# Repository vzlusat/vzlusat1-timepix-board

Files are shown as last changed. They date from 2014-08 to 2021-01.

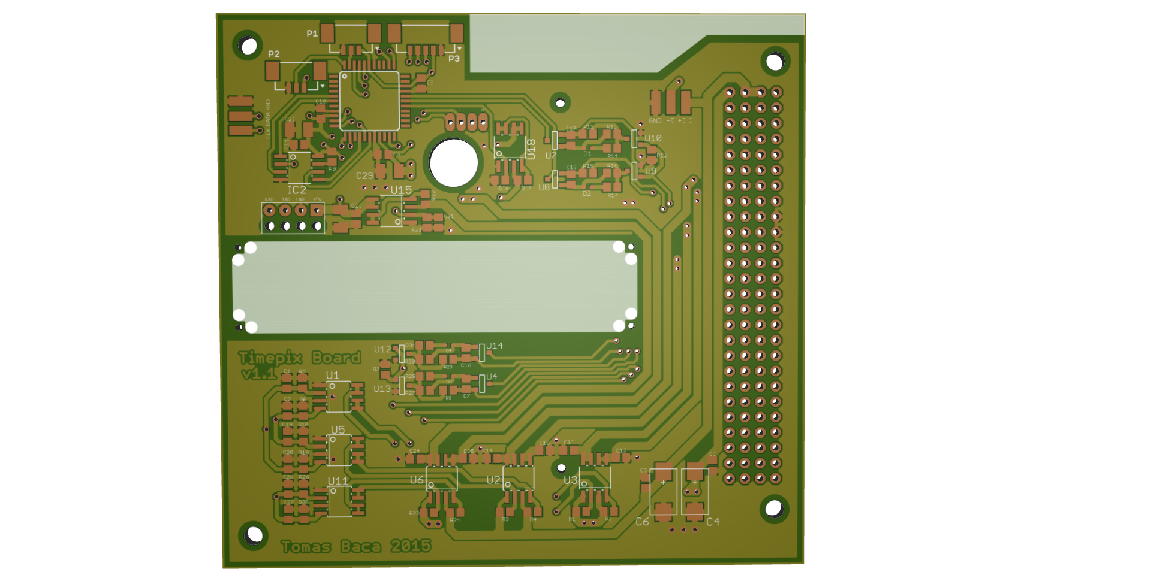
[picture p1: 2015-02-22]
hardware/timepix_board/timepix_board_board.png

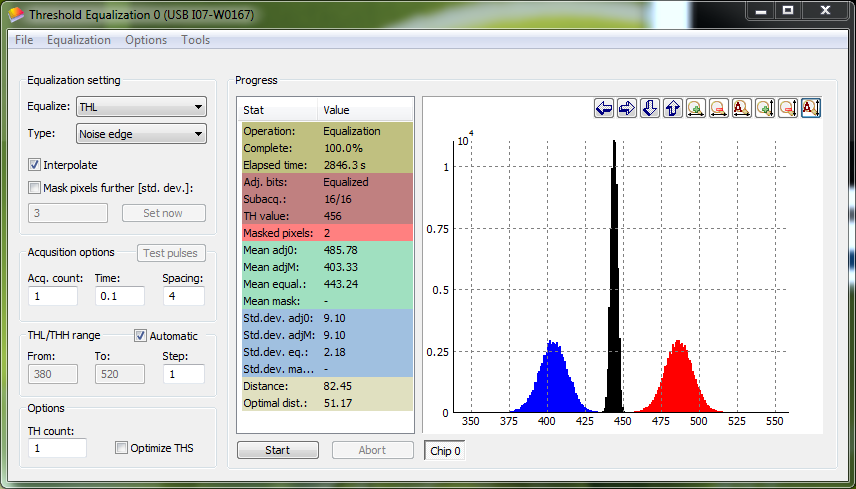
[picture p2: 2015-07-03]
software/EqualizationParser/equalization_fligh_model/equalization.PNG

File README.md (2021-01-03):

# VZLUSAT-1 Timepix board materials

## Publications

```
Baca, T., et al.
"Timepix in LEO Orbit onboard the VZLUSAT-1 Nanosatellite:
1-year of Space Radiation Dosimetry Measurements."
Journal of Instrumentation 13.11 (2018): C11010.
```

```
Baca, T., et al.
"Miniaturized X-ray telescope for VZLUSAT-1 nanosatellite with Timepix detector."
Journal of Instrumentation 11.10 (2016): C10007.
```

```
Urban, Martin, et al.
"VZLUSAT-1: Nanosatellite with miniature lobster eye X-ray telescope
and qualification of the radiation shielding composite for space application."
Acta Astronautica 140 (2017): 96-104.
```

```
Daniel, Vladimír, et al.
"In-Orbit Commissioning of Czech Nanosatellite VZLUSAT-1 for the QB50 Mission
with a Demonstrator of a Miniaturised Lobster-Eye X-Ray Telescope
and Radiation Shielding Composite Materials."
Space Science Reviews 215.5 (2019): 40.
```

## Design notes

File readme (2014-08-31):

The pure core of FreeRTOS with drivers used on ATXMega128A4U in the VZLUSat project.

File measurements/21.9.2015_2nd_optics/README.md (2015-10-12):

Měření 21.9.2015
================

Probíhalo testování nové (druhé) x-ray optiky v komeře v Rigaku.

Legenda je v mereni_21.9.2015.pdf

- EQM deska s letovým firmware
- nejdříve měření před odsátím atmosféry, s proudem do x-ray zdroje 0.1mA, timepix v čítacím módu, expozice od 1ms do 100ms
- poté několik měření se zaplou filtrací během odsávání atmosfery s expozicí 1ms, poud 0.01mA, čítací mód
- nakonec ve vakuu průběh expozic od 1ms do 100ms s proudem 0.1mA, čítacím módem

snímek #625 s umístěným výkonným nelegálním zářičem za medipixem (mimo komoru) 

legenda k názvům souborů:
- _1 je originální (nezmenšený) snímek
- _2 je binning8
- _4 je binning16
- _8 je binning32
- _16 jsou součty řádků a sloupců
- _32 je energetický histogram

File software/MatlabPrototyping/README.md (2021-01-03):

# A prototyping Matlab control scripts for the Timepix board

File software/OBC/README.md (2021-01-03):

# OBC-side of the Timepix board software API

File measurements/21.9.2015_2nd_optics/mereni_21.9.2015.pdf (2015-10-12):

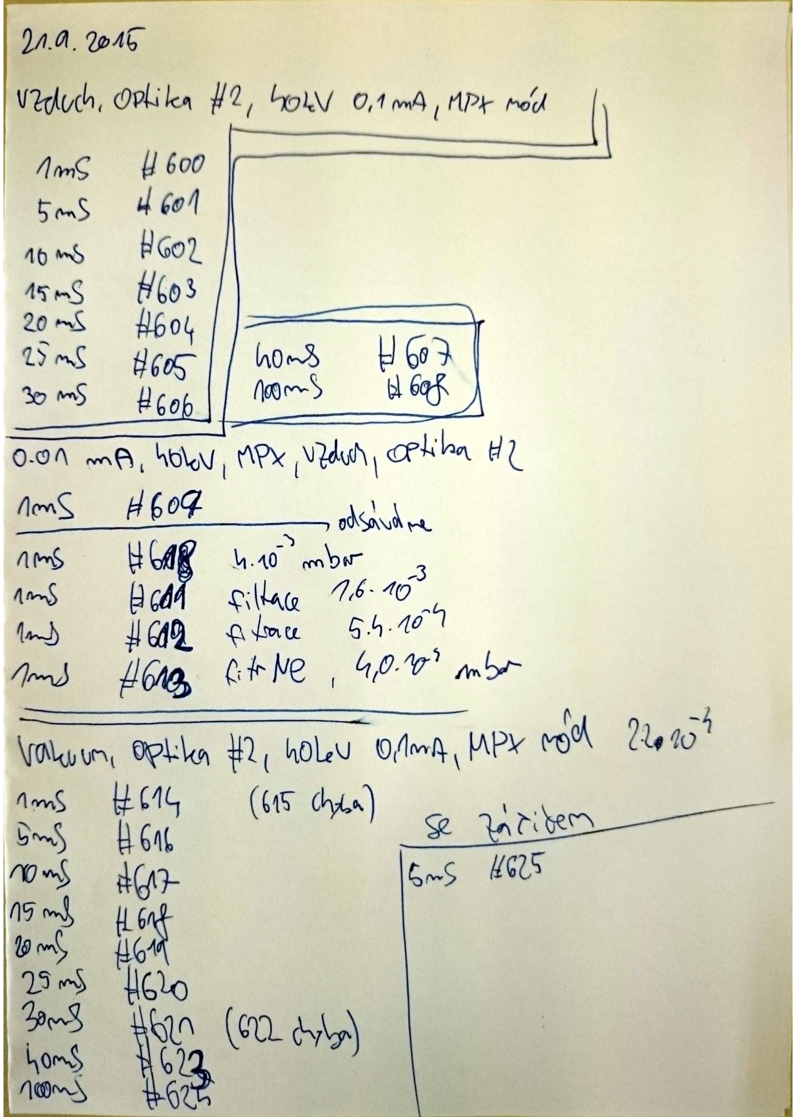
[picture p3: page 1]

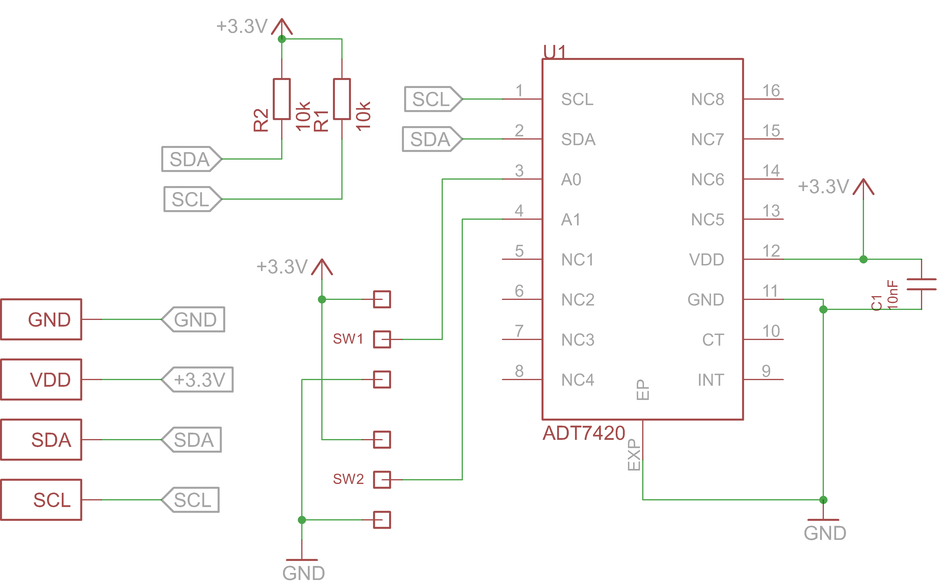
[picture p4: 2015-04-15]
hardware/ADT7420_board/therm_board_schema.png

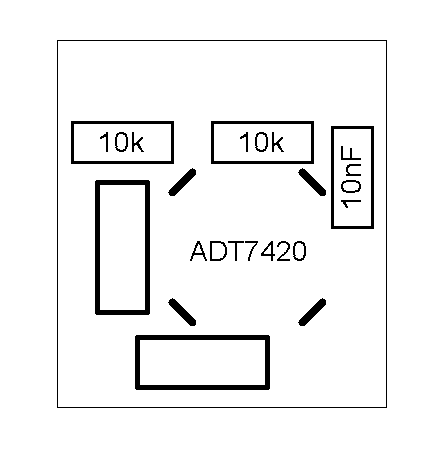
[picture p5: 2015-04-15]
hardware/ADT7420_board/therm_board_osazovak.png

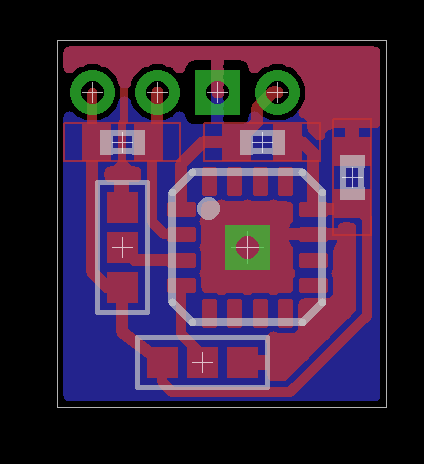
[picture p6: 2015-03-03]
hardware/ADT7420_board/therm_board.png

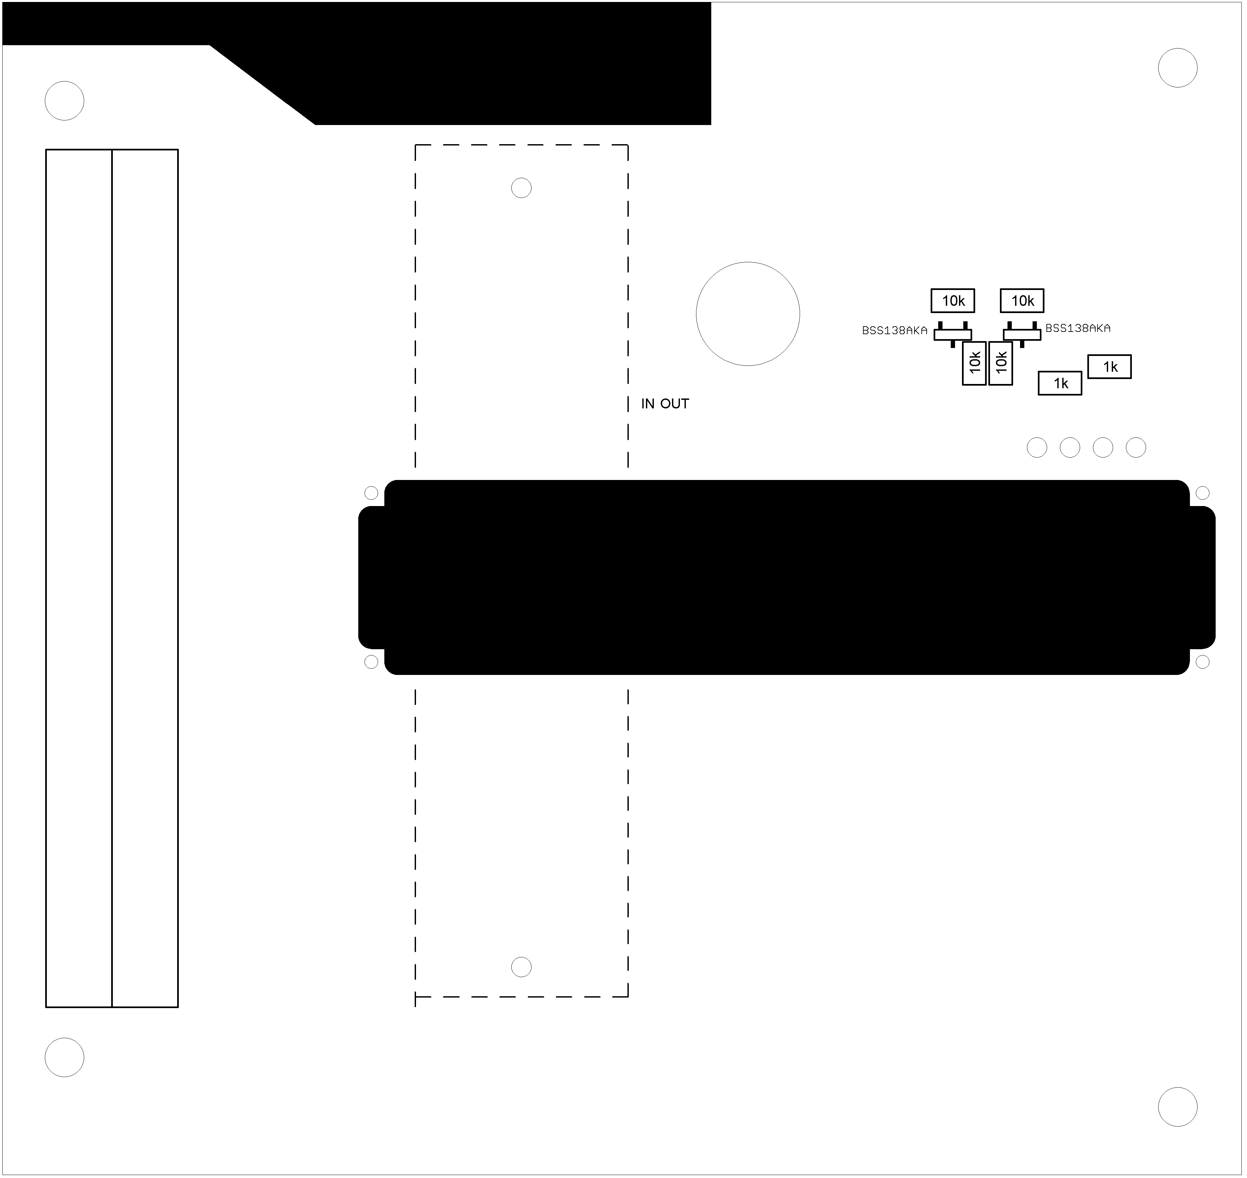
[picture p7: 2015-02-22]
hardware/timepix_board/part_bottom.png

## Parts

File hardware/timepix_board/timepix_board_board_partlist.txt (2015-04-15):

Partlist

Exported from medipix.sch at 19.3.2015 9:49:41

EAGLE Version 6.5.0 Copyright (c) 1988-2013 CadSoft

Assembly variant: 

Part     Value             Device             Package           Library             Sheet

C1       100n              CAPACITOR_CERAMIC  R0805             medipix             1
C2       100n              CAPACITOR_CERAMIC  R0805             medipix             1
C3       100n              CAPACITOR_CERAMIC  R0805             medipix             1
C4       220u              CAPACITOR_TANTAL_D D                 medipix             1
C5       100n              CAPACITOR_CERAMIC  R0805             medipix             1
C6       220u              CAPACITOR_TANTAL_D D                 medipix             1
C7       15nF              CAPACITOR_CERAMIC  R0805             medipix             1
C8       100n              CAPACITOR_CERAMIC  R0805             medipix             1
C9       100n              CAPACITOR_CERAMIC  R0805             medipix             1
C10      100n              CAPACITOR_CERAMIC  R0805             medipix             1
C11      100n              CAPACITOR_CERAMIC  R0805             medipix             1
C12      100n              CAPACITOR_CERAMIC  R0805             medipix             1
C13      100n              CAPACITOR_CERAMIC  R0805             medipix             1
C14      100n              CAPACITOR_CERAMIC  R0805             medipix             1
C15      100n              CAPACITOR_CERAMIC  R0805             medipix             1
C16      15nF              CAPACITOR_CERAMIC  R0805             medipix             1
C17      15nF              CAPACITOR_CERAMIC  R0805             medipix             1
C18      15nF              CAPACITOR_CERAMIC  R0805             medipix             1
C19      100n              CAPACITOR_CERAMIC  R0805             medipix             1
C20      100n              CAPACITOR_CERAMIC  R0805             medipix             1
C21      100n              CAPACITOR_CERAMIC  R0805             medipix             1
C22      100u              CAPACITOR_TANTAL_B SMC_B             medipix             1
C23      100n              CAPACITOR_CERAMIC  R0805             medipix             1
C24      100n              CAPACITOR_CERAMIC  R0805             medipix             1
C25      100n              CAPACITOR_CERAMIC  R0805             medipix             1
C26      100n              CAPACITOR_CERAMIC  R0805             medipix             1
C27      100n              CAPACITOR_CERAMIC  R0805             medipix             1
C28      100u              CAPACITOR_TANTAL_B SMC_B             medipix             1
C29      100u              CAPACITOR_TANTAL_B SMC_B             medipix             1
CLK      CLK               PIN                PIN               medipix             1
D1       BAS70             BAS70              SOD523            medipix             1
D2       BAS70             BAS70              SOD523            medipix             1
D3       BAS70             BAS70              SOD523            medipix             1
D4       BAS70             BAS70              SOD523            medipix             1
DATA     DATA              PIN                PIN               medipix             1
GND      GND               PIN                PIN               medipix             1
GND1     GND               PIN                PIN               medipix             1
GND25    +3.3              PIN                PIN               medipix             1
GND28    +5                PIN                PIN               medipix             1
H1       H1                H1                 H-KONEKTOR        medipix             1
H2       H2                H2                 H-KONEKTOR        medipix             1
IC1      AVR_XMEGA_A4U44A  AVR_XMEGA_A4U44A   TQFP44            medipix             1
IC2      FM25H20           FM25H20            SOIC08            medipix             1
MP       MEDIPIX_CONNECTOR MEDIPIX_CONNECTOR  MEDIPIX_CONNECTOR medipix             1
P1       PICOBLADE         53398-0310         53398-0310        con-molex-picoblade 1
P2       PICOBLADE         53398-0310         53398-0310        con-molex-picoblade 1
P3       PICOBLADE         53398-0510         53398-0510        con-molex-picoblade 1
R1       100k              RESISTOR0805       R0805             medipix             1
R2       100k              RESISTOR0805       R0805             medipix             1
R3       100k              RESISTOR0805       R0805             medipix             1
R4       100k              RESISTOR0805       R0805             medipix             1
R5       100k              RESISTOR0805       R0805             medipix             1
R6       100k              RESISTOR0805       R0805             medipix             1
R7       100k              RESISTOR0805       R0805             medipix             1
R8       100k              RESISTOR0805       R0805             medipix             1
R9       100k              RESISTOR0805       R0805             medipix             1
R10      100k              RESISTOR0805       R0805             medipix             1
R11      100k              RESISTOR0805       R0805             medipix             1
R12      100k              RESISTOR0805       R0805             medipix             1
R13      330k              RESISTOR0805       R0805             medipix             1
R14      1k5               RESISTOR0805       R0805             medipix             1
R15      100k              RESISTOR0805       R0805             medipix             1
R16      330k              RESISTOR0805       R0805             medipix             1
R17      1k5               RESISTOR0805       R0805             medipix             1
R18      100k              RESISTOR0805       R0805             medipix             1
R19      10k               RESISTOR0805       R0805             medipix             1
R20      10k               RESISTOR0805       R0805             medipix             1
R21      100k              RESISTOR0805       R0805             medipix             1
R22      100k              RESISTOR0805       R0805             medipix             1
R23      100k              RESISTOR0805       R0805             medipix             1
R24      100k              RESISTOR0805       R0805             medipix             1
R25      100k              RESISTOR0805       R0805             medipix             1
R26      100k              RESISTOR0805       R0805             medipix             1
R27      330k              RESISTOR0805       R0805             medipix             1
R28      1k5               RESISTOR0805       R0805             medipix             1
R29      100k              RESISTOR0805       R0805             medipix             1
R30      330k              RESISTOR0805       R0805             medipix             1
R31      1k5               RESISTOR0805       R0805             medipix             1
R32      10k               RESISTOR0805       R0805             medipix             1
R33      10k               RESISTOR0805       R0805             medipix             1
R34      1k                RESISTOR0805       R0805             medipix             1
R35      1k                RESISTOR0805       R0805             medipix             1
R36      100k              RESISTOR0805       R0805             medipix             1
R37      100k              RESISTOR0805       R0805             medipix             1
TXD1     IN                PIN                PIN               medipix             1
TXD2     OUT               PIN                PIN               medipix             1
U$1      THERM             THERM              THERM             medipix             1
U1       IRF7313           IRF7313            SOIC08            medipix             1
U2       IRF7328           IRF7328            SOIC08            medipix             1
U3       IRF7328           IRF7328            SOIC08            medipix             1
U4       BSS84             BSS84              SOT-23            medipix             1
U5       IRF7313           IRF7313            SOIC08            medipix             1
U6       IRF7328           IRF7328            SOIC08            medipix             1
U7       BSS84             BSS84              SOT-23            medipix             1
U8       BSS84             BSS84              SOT-23            medipix             1
U9       BSS138AKA         BSS138AKA          SOT-23            medipix             1
U10      BSS138AKA         BSS138AKA          SOT-23            medipix             1
U11      IRF7313           IRF7313            SOIC08            medipix             1
U12      BSS138AKA         BSS138AKA          SOT-23            medipix             1
U13      BSS138AKA         BSS138AKA          SOT-23            medipix             1
U14      BSS84             BSS84              SOT-23            medipix             1
U15      IRF7319           IRF7319            SOIC08            medipix             1
U16      BSS138AKA         BSS138AKA          SOT-23            medipix             1
U17      BSS138AKA         BSS138AKA          SOT-23            medipix             1
U18      IRF7319           IRF7319            SOIC08            medipix             1

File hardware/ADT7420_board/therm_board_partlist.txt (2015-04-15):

Partlist

Exported from thermo_board.brd at 19.3.2015 9:47:04

EAGLE Version 6.5.0 Copyright (c) 1988-2013 CadSoft

Assembly variant: 

Part     Value             Package         Library    Position (inch)       Orientation

C1       10nF              R0402           thermo_lib (0.295 0.23)          R270
R1       10k               R0402           thermo_lib (0.205 0.265)         R0
R2       10k               R0402           thermo_lib (0.065 0.265)         R180
U1       ADT7420           LFCSP16         thermo_lib (0.19 0.16)           R0

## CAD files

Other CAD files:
hardware/cooler/cooler1.dwg
software/usb_lite_firmware_modified/Medipix.OBJ

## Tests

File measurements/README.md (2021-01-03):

# Measurement during prototyping

The orbital measurements can be proccessed using [https://github.com/vzlusat/vzlusat1-timepix-decoder](https://github.com/vzlusat/vzlusat1-timepix-decoder) and found here processed: [https://github.com/vzlusat/vzlusat1-timepix-data](https://github.com/vzlusat/vzlusat1-timepix-data)

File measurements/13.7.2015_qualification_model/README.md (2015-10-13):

Měření 13.7.2015
================

Legenda je uložena v mereni-13.7.2015-EQM.pdf

Probíhalo měření v komoře v Rigaku s EQM HW, ve vakuu a bez optiky.

Nejdříve bylo uděláno pár snímku před a během odčerpávání vzduchu z komory.

Všechna měření, až na poslední (vyznačené v legendě) jsou s výkonem x-ray zdroje 40kV, 0.1mA, poslední je s 0.01mA.

Měření se stává z několika sérií s expozicemi od 1ms do 10 až 30ms.

Všchna měření měla zaplou filtraci, nicméně mimo post-processovaného výstupu se ukládaly i originální snímky (soubory s _o).

Konvence pojmenování souborů: soubor s "o" nakonci (např. image_513o.mat) obsahuje originální snímek, soubor s "p" nakonci (image_513p.mat) obsahuje příslušný zpracovaný snímek (tedy postprocess, filtrace, zmenšenina, podle toho, co bylo zapnuté).

POZOR, BĚHEM TOHOTO MěřENí BYLA V SOFTWARU CHYBA, V TOT REžIMU SE ZAOKROUHLOVALO DOLU, TEDY ZMIZELY PIXELI S ENERGIí < 43. MěřENí V MÓDU MPX JSOU V POřáDKU.

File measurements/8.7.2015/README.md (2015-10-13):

Měření 8.7.2015
================

Legenda se nachází v mereni_8.7.2015.pdf

Probíhalo měření v komoře v Rigaku s EQM HW, na vzduchu, nejdříve s a poté bez krycího sklíčka na detektoru.

POZOR, BĚHEM TOHOTO MěřENí BYLA V SOFTWARU CHYBA, V TOT REžIMU SE ZAOKROUHLOVALO DOLU, TEDY ZMIZELY PIXELI S ENERGIí < 43. MěřENí V MÓDU MPX JSOU V POřáDKU.

Nejdříve bylo uděláno pár snímku před a po sundání krycího sklíčka.

Zajímavé (srovnatelné) jsou tedy snímky 420, 422 a 423, které jsou v MPX módu a bez krycího sklíčka.

Poté jsme se jali měřiti s optikou. Ukládány byly různé varianty výstupu pro expozice od 1ms do 200ms, vše na vzduchu a s filtrací.

Snímky pravděpodobně nejsou vhodné pro srovnání vzhledem k expozici ve vzduchu.

Konvence pojmenování souborů: soubor s "o" nakonci (např. image_513o.mat) obsahuje originální snímek, soubor s "p" nakonci (image_513p.mat) obsahuje příslušný zpracovaný snímek (tedy postprocess, filtrace, zmenšenina, podle toho, co bylo zapnuté).

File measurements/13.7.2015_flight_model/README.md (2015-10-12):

Měření 13.7.2015
================

Měření s tohoto dne se zaměřovala na test letového hardwaru. 

POZOR, BĚHEM TOHOTO MěřENí BYLA V SOFTWARU CHYBA, V TOT REžIMU SE ZAOKROUHLOVALO DOLU, TEDY ZMIZELY PIXELI S ENERGIí < 43. MěřENí V MÓDU MPX JSOU V POřáDKU.

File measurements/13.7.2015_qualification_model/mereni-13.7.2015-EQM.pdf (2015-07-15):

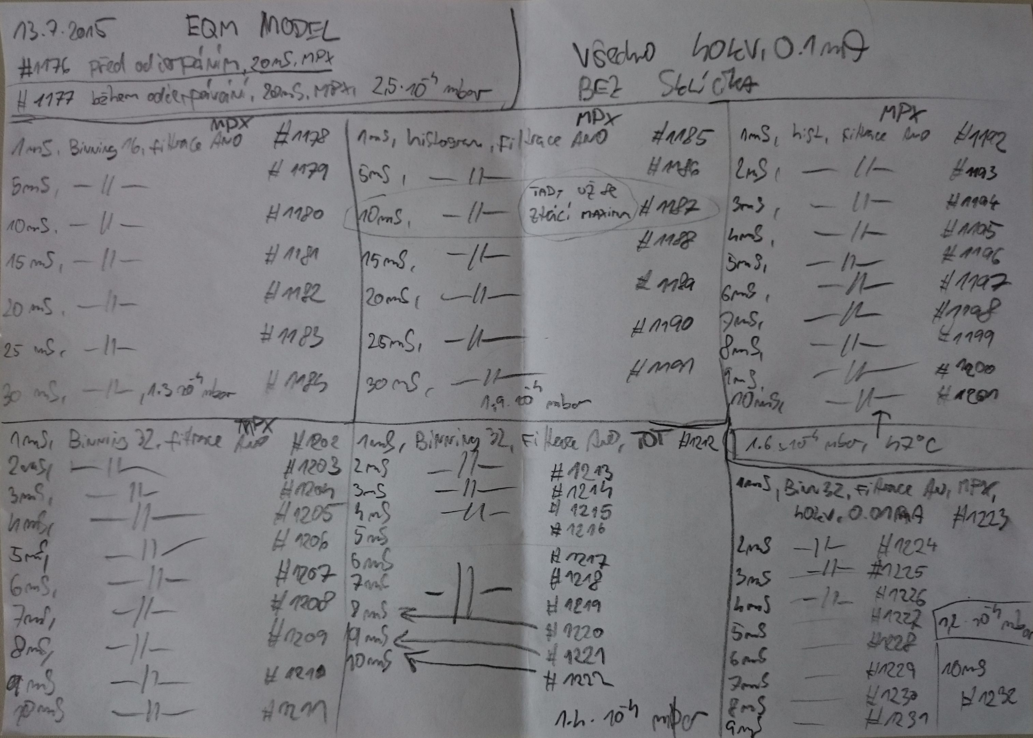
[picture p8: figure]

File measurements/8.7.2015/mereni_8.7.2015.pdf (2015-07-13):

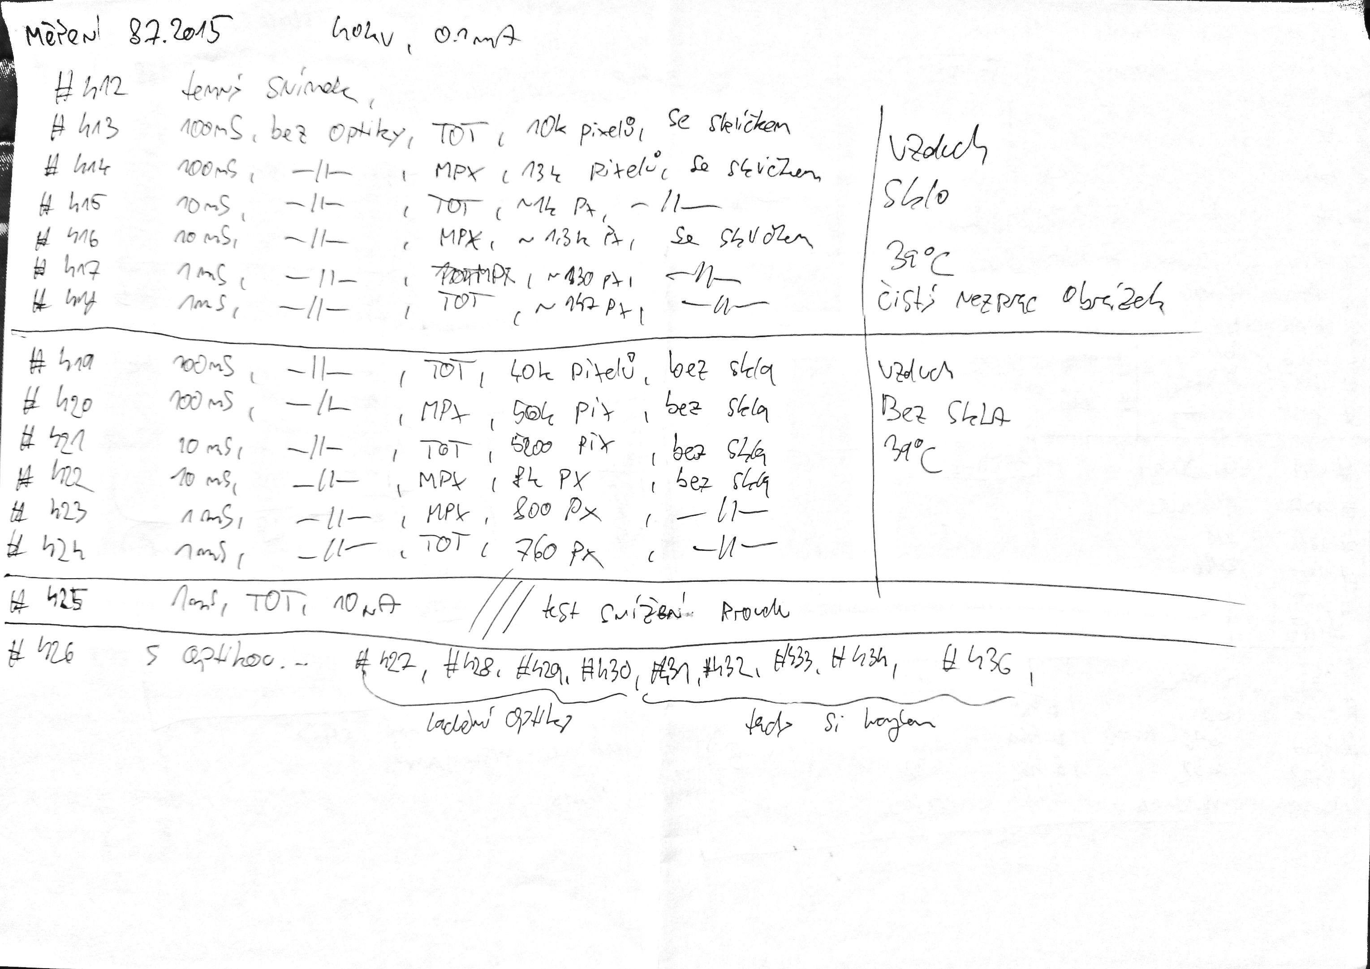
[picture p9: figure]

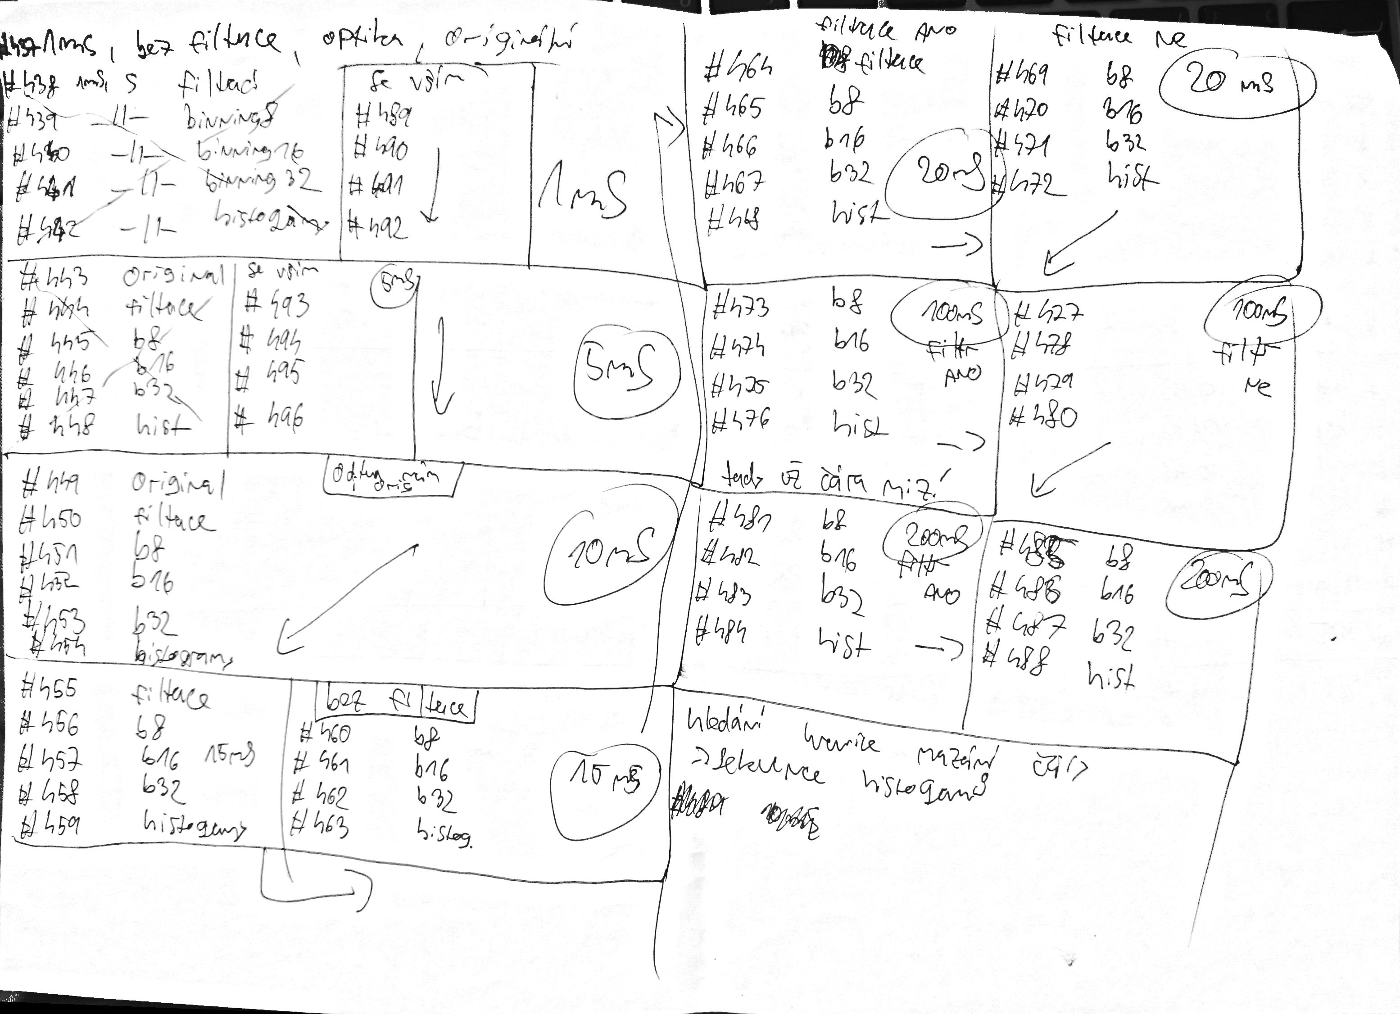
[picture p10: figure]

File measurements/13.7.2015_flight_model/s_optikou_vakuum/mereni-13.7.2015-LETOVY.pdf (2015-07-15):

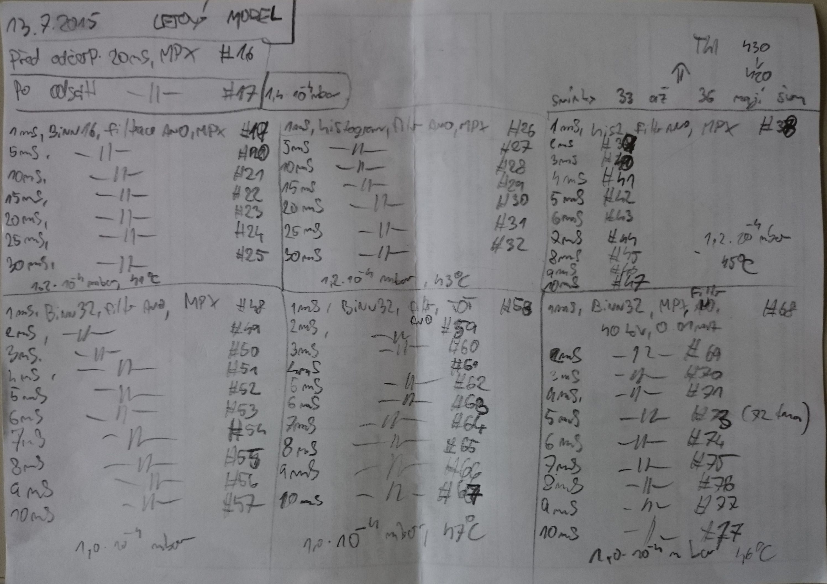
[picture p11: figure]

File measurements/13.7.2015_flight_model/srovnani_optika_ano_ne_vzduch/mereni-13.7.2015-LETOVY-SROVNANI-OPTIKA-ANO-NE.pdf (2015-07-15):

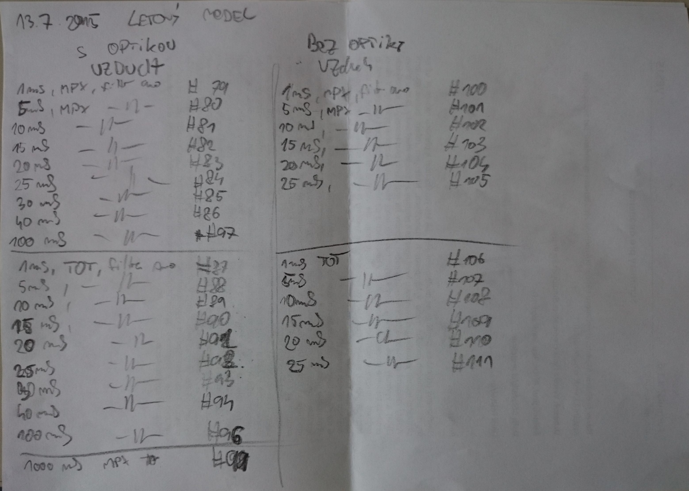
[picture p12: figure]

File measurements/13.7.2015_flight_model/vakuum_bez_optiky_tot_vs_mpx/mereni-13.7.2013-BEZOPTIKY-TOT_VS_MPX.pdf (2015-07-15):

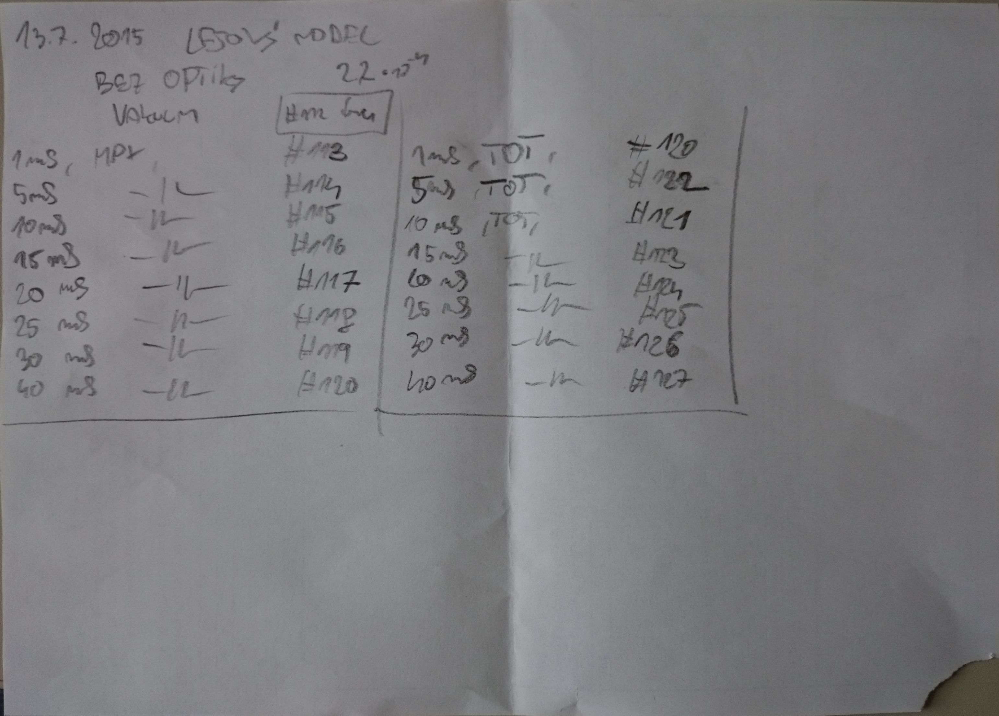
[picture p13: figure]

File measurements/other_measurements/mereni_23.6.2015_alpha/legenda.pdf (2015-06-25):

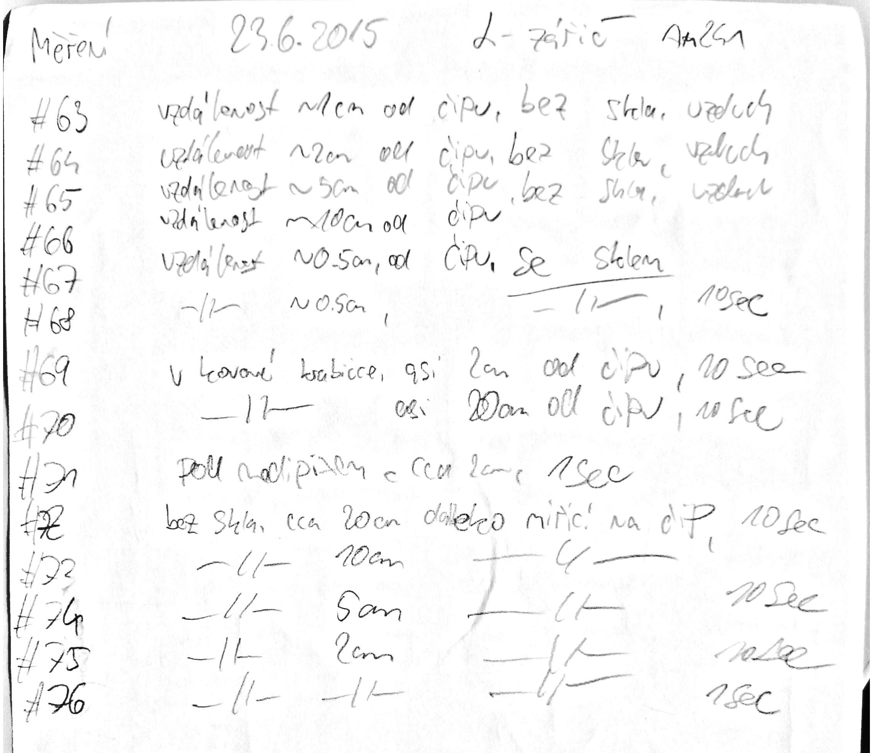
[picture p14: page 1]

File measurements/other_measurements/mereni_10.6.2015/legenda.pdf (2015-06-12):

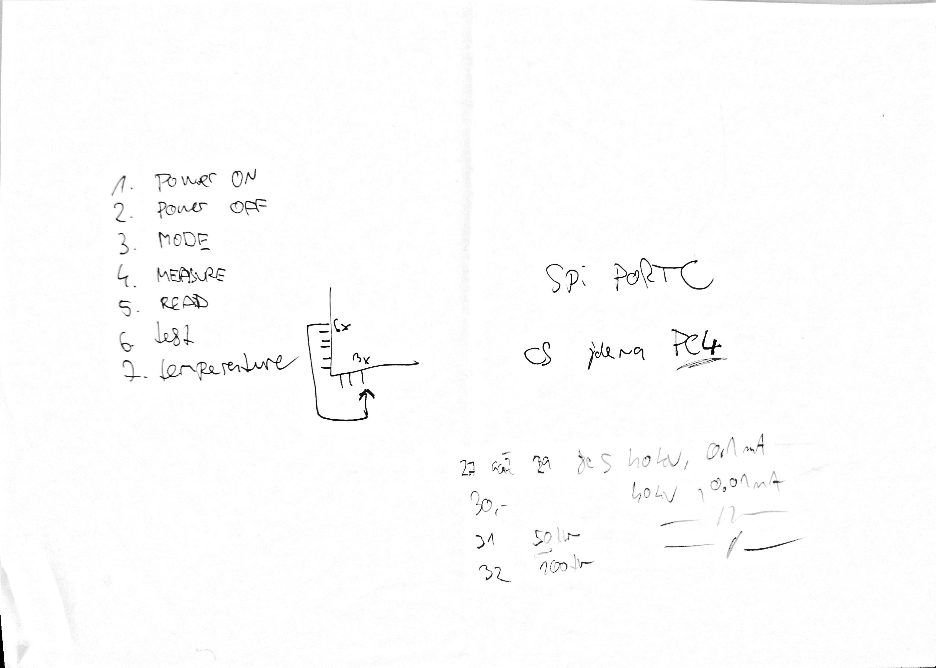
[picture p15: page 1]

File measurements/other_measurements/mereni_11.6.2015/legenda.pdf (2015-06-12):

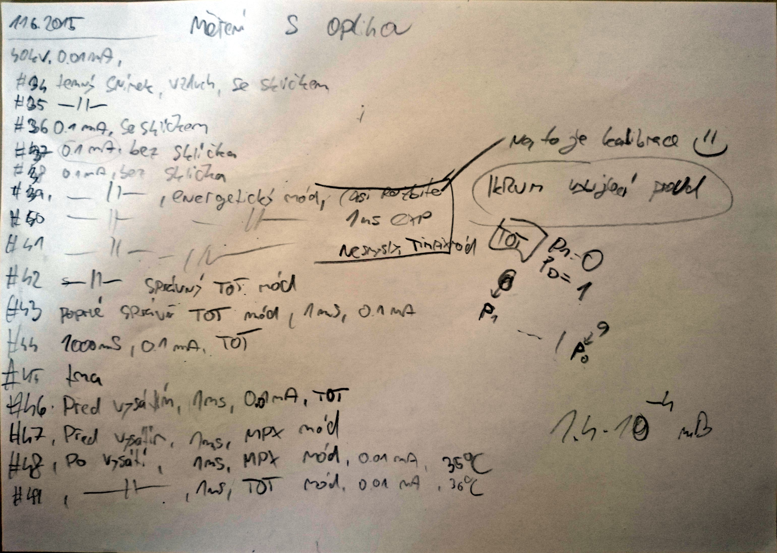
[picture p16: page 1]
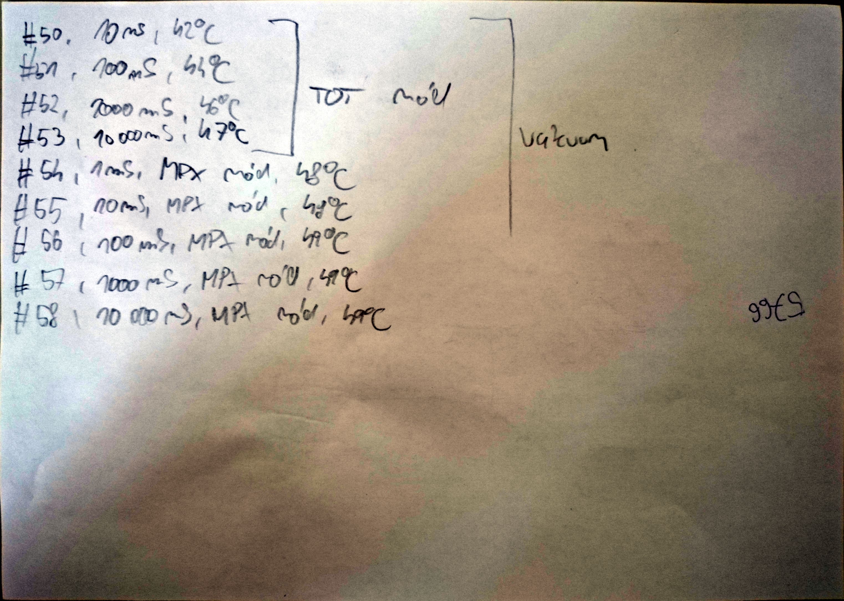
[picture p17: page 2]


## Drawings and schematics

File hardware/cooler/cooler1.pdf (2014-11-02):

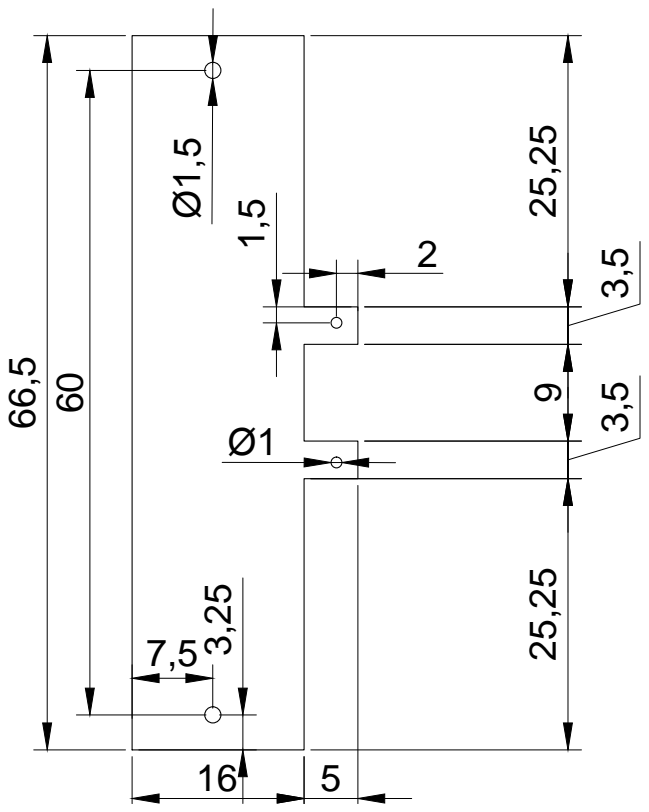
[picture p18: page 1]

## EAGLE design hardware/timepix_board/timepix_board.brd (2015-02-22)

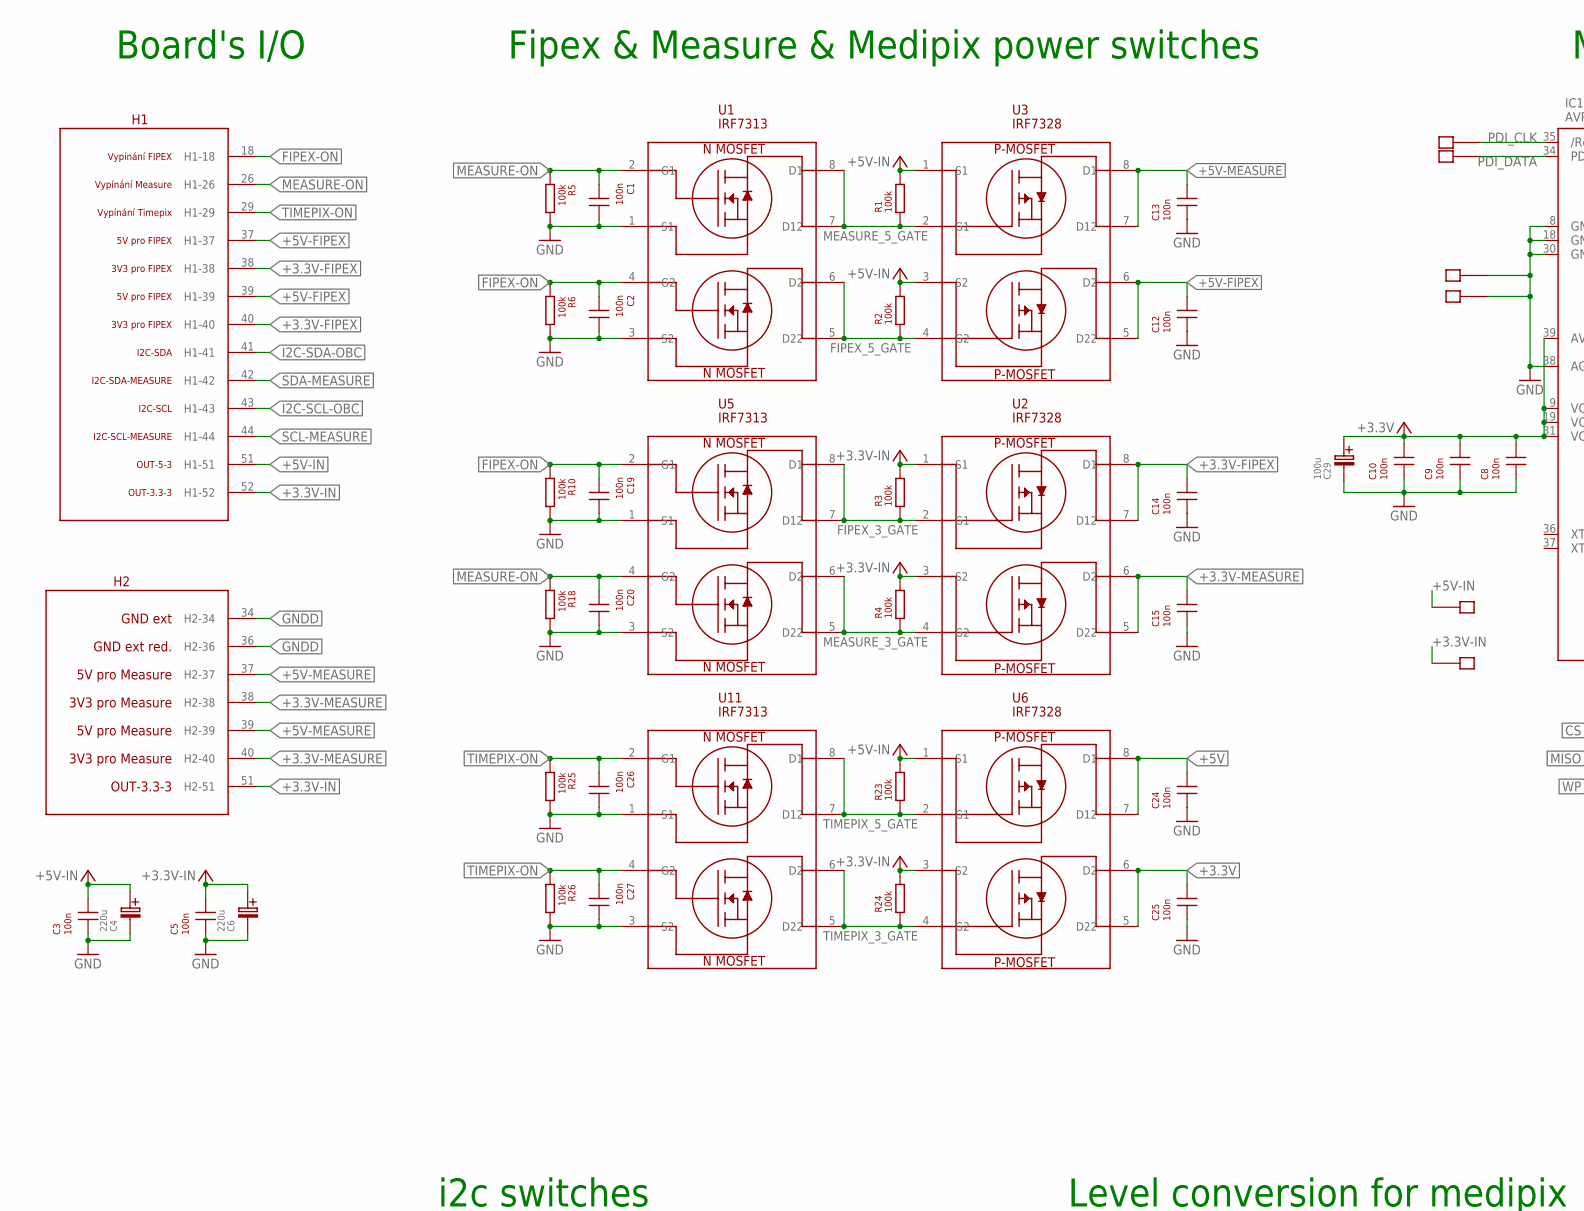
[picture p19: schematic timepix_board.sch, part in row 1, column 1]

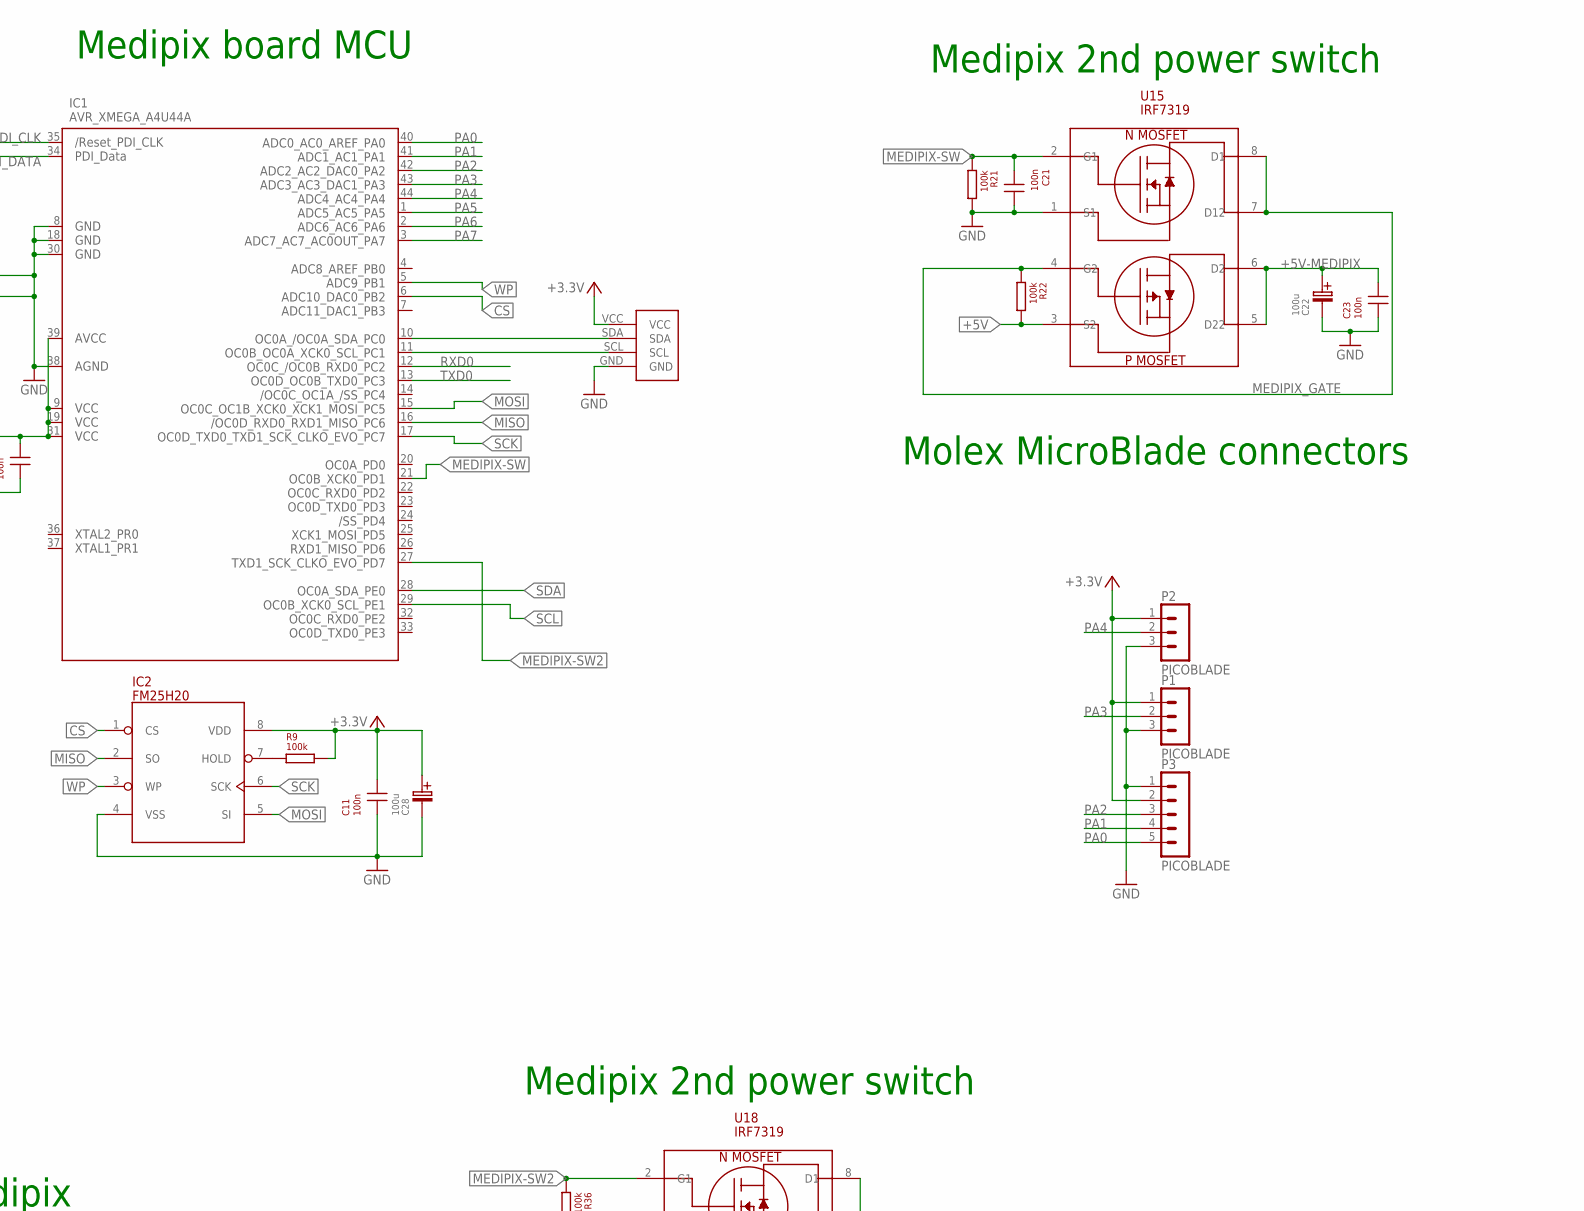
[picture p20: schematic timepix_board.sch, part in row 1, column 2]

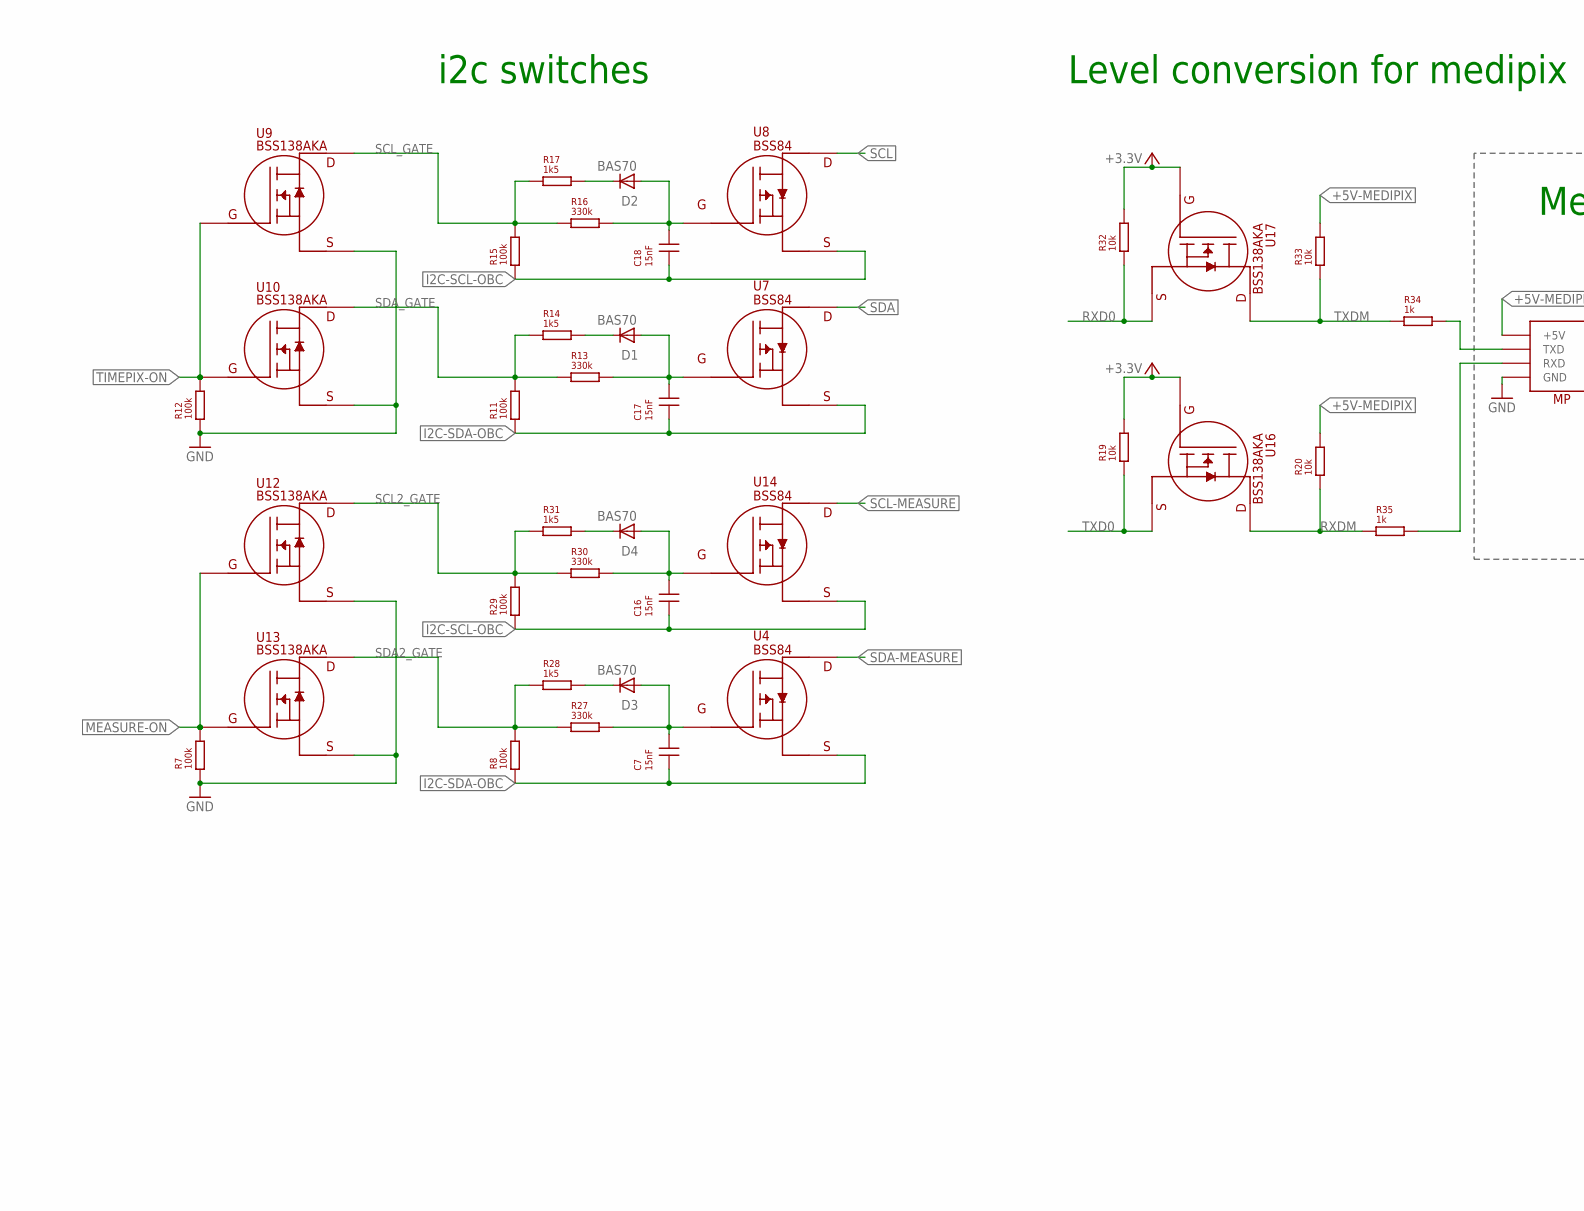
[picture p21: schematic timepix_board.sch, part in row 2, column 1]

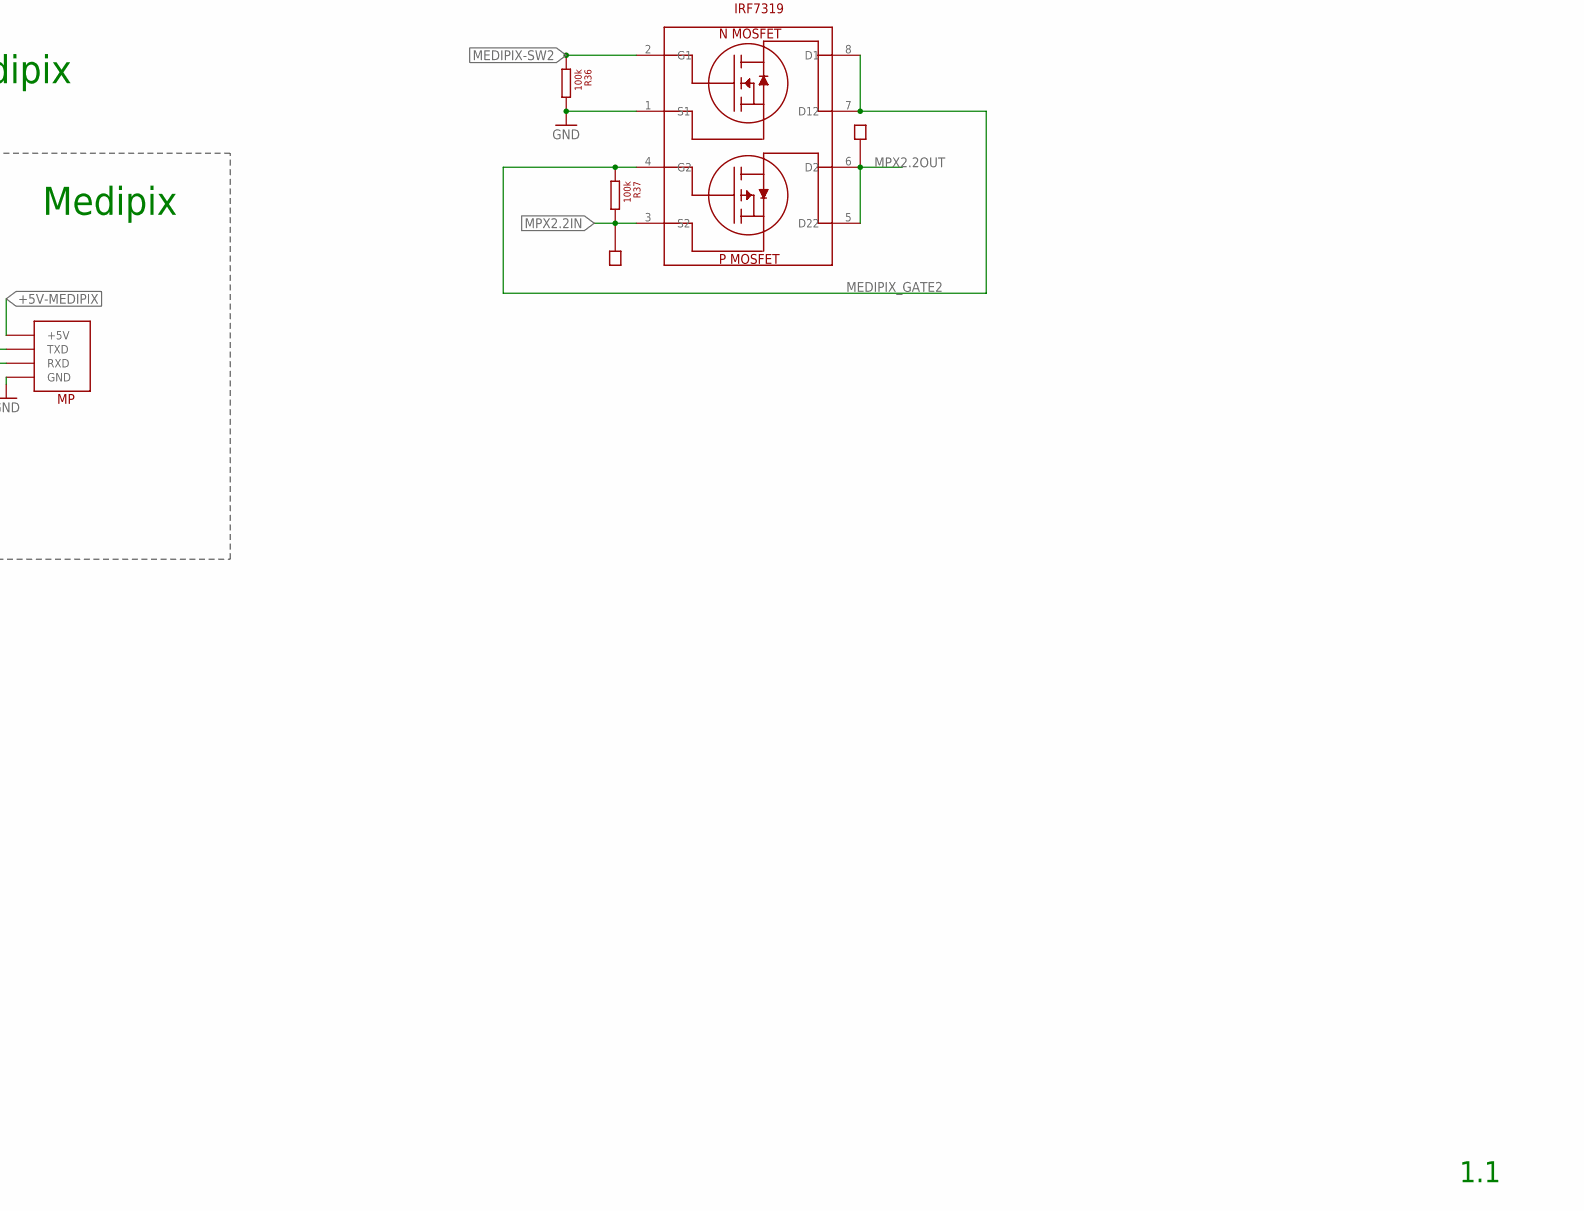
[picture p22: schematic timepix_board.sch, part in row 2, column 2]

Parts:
C1, C2, C3, C5, C8, C9, C10, C11, C12, C13, C14, C15, C19, C20, C21, C23, C24, C25, C26, C27: 100n; R0805
C4, C6: 220u; D
C7, C16, C17, C18: 15nF; R0805
C22, C28, C29: 100u; SMC_B
CLK: CLK; PIN
D1, D2, D3, D4: BAS70; SOD523
DATA: DATA; PIN
GND, GND1: GND; PIN
GND25: +3.3; PIN
GND28: +5; PIN
H1: H1; H-KONEKTOR
H2: H2; H-KONEKTOR
IC1: AVR_XMEGA_A4U44A; TQFP44
IC2: FM25H20; SOIC08
MP: MEDIPIX_CONNECTOR
P1, P2: PICOBLADE; 53398-0310
P3: PICOBLADE; 53398-0510
R1, R2, R3, R4, R5, R6, R7, R8, R9, R10, R11, R12, R15, R18, R21, R22, R23, R24, R25, R26, R29, R36, R37: 100k; R0805
R13, R16, R27, R30: 330k; R0805
R14, R17, R28, R31: 1k5; R0805
R19, R20, R32, R33: 10k; R0805
R34, R35: 1k; R0805
TXD1: IN; PIN
TXD2: OUT; PIN
U1, U5, U11: IRF7313; SOIC08
U2, U3, U6: IRF7328; SOIC08
U4, U7, U8, U14: BSS84; SOT-23
U9, U10, U12, U13, U16, U17: BSS138AKA; SOT-23
U15, U18: IRF7319; SOIC08
U$1: THERM

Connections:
+3.3V: C8.2, C9.2, C10.2, C11.2, C25.2, C28.+ (C_EL+), C29.+ (C_EL+), IC1.9 (VCC1), IC1.19 (VCC2), IC1.31 (VCC3), IC1.39 (AVCC), IC2.8 (VDD), P1.1, P2.1, P3.2, R9.2, R19.2, R32.2, U6.5 (D22), U6.6 (D2), U16.1 (G), U17.1 (G), U$1.VCC
+3.3V-FIPEX: C14.2, H1.38 (H1-38), H1.40 (H1-40), U2.7 (D12), U2.8 (D1)
+3.3V-IN: C5.2, C6.+ (C_EL+), GND25.P$1, H1.52 (H1-52), H2.51 (H2-51), R3.2, R4.2, R24.2, U2.1 (S1), U2.3 (S2), U6.3 (S2)
+3.3V-MEASURE: C15.2, H2.38 (H2-38), H2.40 (H2-40), U2.5 (D22), U2.6 (D2)
+5V: C24.2, R22.2, U6.7 (D12), U6.8 (D1), U15.3 (S2)
+5V-FIPEX: C12.2, H1.37 (H1-37), H1.39 (H1-39), U3.5 (D22), U3.6 (D2)
+5V-IN: C3.2, C4.+ (C_EL+), GND28.P$1, H1.51 (H1-51), R1.2, R2.2, R23.2, U3.1 (S1), U3.3 (S2), U6.1 (S1)
+5V-MEASURE: C13.2, H2.37 (H2-37), H2.39 (H2-39), U3.7 (D12), U3.8 (D1)
+5V-MEDIPIX: C22.+ (C_EL+), C23.2, MP.5V (+5V), R20.2, R33.2, U15.5 (D22), U15.6 (D2)
CS: IC1.6 (PB2), IC2.1 (CS)
FIPEX-ON: C2.1, C19.1, H1.18 (H1-18), R6.1, R10.1, U1.4 (G2), U5.2 (G1)
FIPEX_3_GATE: R3.1, U2.2 (G1), U5.7 (D12), U5.8 (D1)
FIPEX_5_GATE: R2.1, U1.5 (D22), U1.6 (D2), U3.4 (G2)
GND: U$1.GND
GNDD: C1.2, C2.2, C3.1, C4.- (C_EL-), C5.1, C6.- (C_EL-), C8.1, C9.1, C10.1, C11.1, C12.1, C13.1, C14.1, C15.1, C19.2, C20.2, C21.2, C22.- (C_EL-), C23.1, C24.1, C25.1, C26.2, C27.2, C28.- (C_EL-), C29.- (C_EL-), GND.P$1, GND1.P$1, H2.34 (H2-34), H2.36 (H2-36), IC1.8 (GND1), IC1.18 (GND2), IC1.30 (GND3), IC1.38 (AGND), IC2.4 (VSS), MP.GND, P1.3, P2.3, P3.1, R5.2, R6.2, R7.1, R10.2, R12.1, R18.2, R21.2, R25.2, R26.2, R36.2, U1.1 (S1), U1.3 (S2), U5.1 (S1), U5.3 (S2), U9.2 (S), U10.2 (S), U11.1 (S1), U11.3 (S2), U12.2 (S), U13.2 (S), U15.1 (S1), U18.1 (S1)
I2C-SCL-OBC: C16.1, C18.1, H1.43 (H1-43), R15.1, R29.1, U8.2 (S), U14.2 (S)
I2C-SDA-OBC: C7.1, C17.1, H1.41 (H1-41), R8.1, R11.1, U4.2 (S), U7.2 (S)
MEASURE-ON: C1.1, C20.1, H1.26 (H1-26), R5.1, R7.2, R18.1, U1.2 (G1), U5.4 (G2), U12.1 (G), U13.1 (G)
MEASURE_3_GATE: R4.1, U2.4 (G2), U5.5 (D22), U5.6 (D2)
MEASURE_5_GATE: R1.1, U1.7 (D12), U1.8 (D1), U3.2 (G1)
MEDIPIX-SW: C21.1, IC1.21 (PD1), R21.1, U15.2 (G1)
MEDIPIX-SW2: IC1.27 (PD7), R36.1, U18.2 (G1)
MEDIPIX_GATE: R22.1, U15.4 (G2), U15.7 (D12), U15.8 (D1)
MEDIPIX_GATE2: R37.1, U18.4 (G2), U18.7 (D12), U18.8 (D1)
MISO: IC1.16 (PC6), IC2.2 (SO)
MOSI: IC1.15 (PC5), IC2.5 (SI)
MPX2.2IN: R37.2, TXD1.P$1, U18.3 (S2)
MPX2.2OUT: TXD2.P$1, U18.5 (D22), U18.6 (D2)
unnamed: D3.C, R28.2
unnamed: C7.2, D3.A, R27.2, U4.1 (G)
unnamed: D2.C, R17.2
unnamed: D1.C, R14.2
unnamed: C17.2, D1.A, R13.2, U7.1 (G)
unnamed: C18.2, D2.A, R16.2, U8.1 (G)
unnamed: IC2.7 (HOLD), R9.1
unnamed: MP.P$4 (TXD), R34.2
unnamed: IC1.11 (PC1), U$1.SCL
unnamed: IC1.10 (PC0), U$1.SDA
unnamed: D4.C, R31.2
unnamed: C16.2, D4.A, R30.2, U14.1 (G)
PA0: IC1.40 (PA0), P3.5
PA1: IC1.41 (PA1), P3.4
PA2: IC1.42 (PA2), P3.3
PA3: IC1.43 (PA3), P1.2
PA4: IC1.44 (PA4), P2.2
PA5: IC1.1 (PA5)
PA6: IC1.2 (PA6)
PA7: IC1.3 (PA7)
PDI_CLK: CLK.P$1, IC1.35 (RESET)
PDI_DATA: DATA.P$1, IC1.34 (PDI_DATA)
RXD0: IC1.12 (PC2), R32.1, U17.2 (S)
RXDM: R20.1, R35.1, U16.3 (D)
RXDMMM: MP.P$3 (RXD), R35.2
SCK: IC1.17 (PC7), IC2.6 (SCK)
SCL: IC1.29 (PE1), U8.3 (D)
SCL2_GATE: R29.2, R30.1, R31.1, U12.3 (D)
SCL-MEASURE: H1.44 (H1-44), U14.3 (D)
SCL_GATE: R15.2, R16.1, R17.1, U9.3 (D)
SDA: IC1.28 (PE0), U7.3 (D)
SDA2_GATE: R8.2, R27.1, R28.1, U13.3 (D)
SDA-MEASURE: H1.42 (H1-42), U4.3 (D)
SDA_GATE: R11.2, R13.1, R14.1, U10.3 (D)
TIMEPIX-ON: C26.1, C27.1, H1.29 (H1-29), R12.2, R25.1, R26.1, U9.1 (G), U10.1 (G), U11.2 (G1), U11.4 (G2)
TIMEPIX_3_GATE: R24.1, U6.4 (G2), U11.5 (D22), U11.6 (D2)
TIMEPIX_5_GATE: R23.1, U6.2 (G1), U11.7 (D12), U11.8 (D1)
TXD0: IC1.13 (PC3), R19.1, U16.2 (S)
TXDM: R33.1, R34.1, U17.3 (D)
WP: IC1.5 (PB1), IC2.3 (WP)

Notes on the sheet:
Board's I/O
Fipex & Measure & Medipix power switches
Medipix board MCU
i2c switches
Molex MicroBlade connectors
Medipix 2nd power switch
1.1
Level conversion for medipix
Medipix

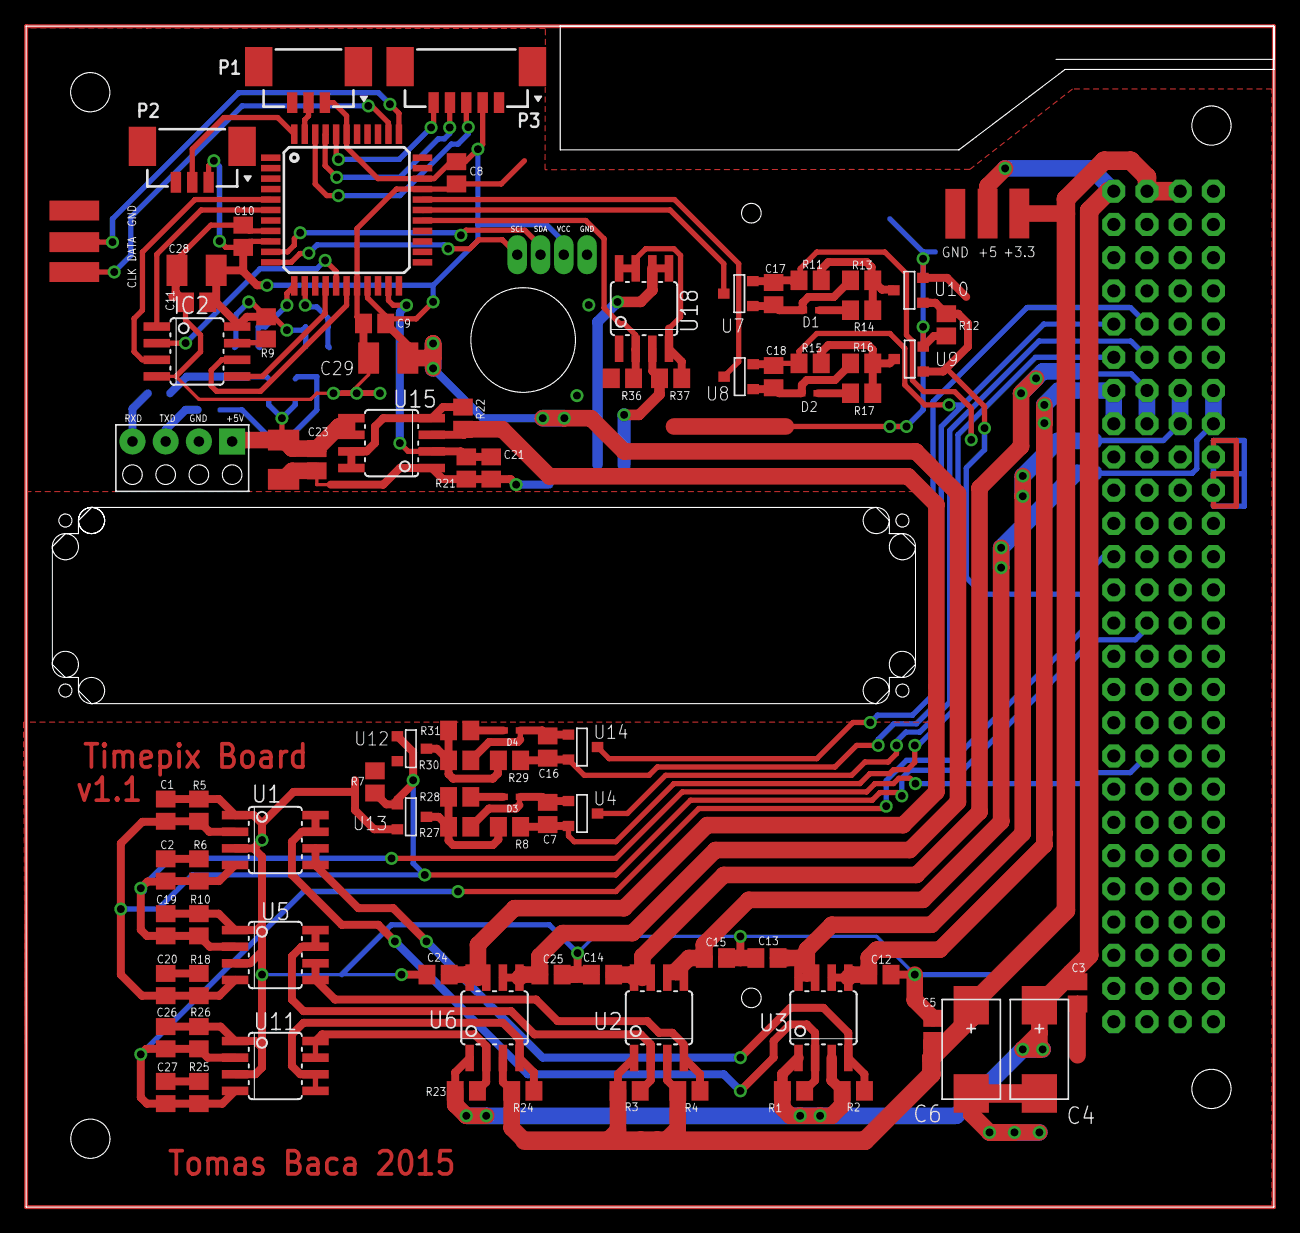
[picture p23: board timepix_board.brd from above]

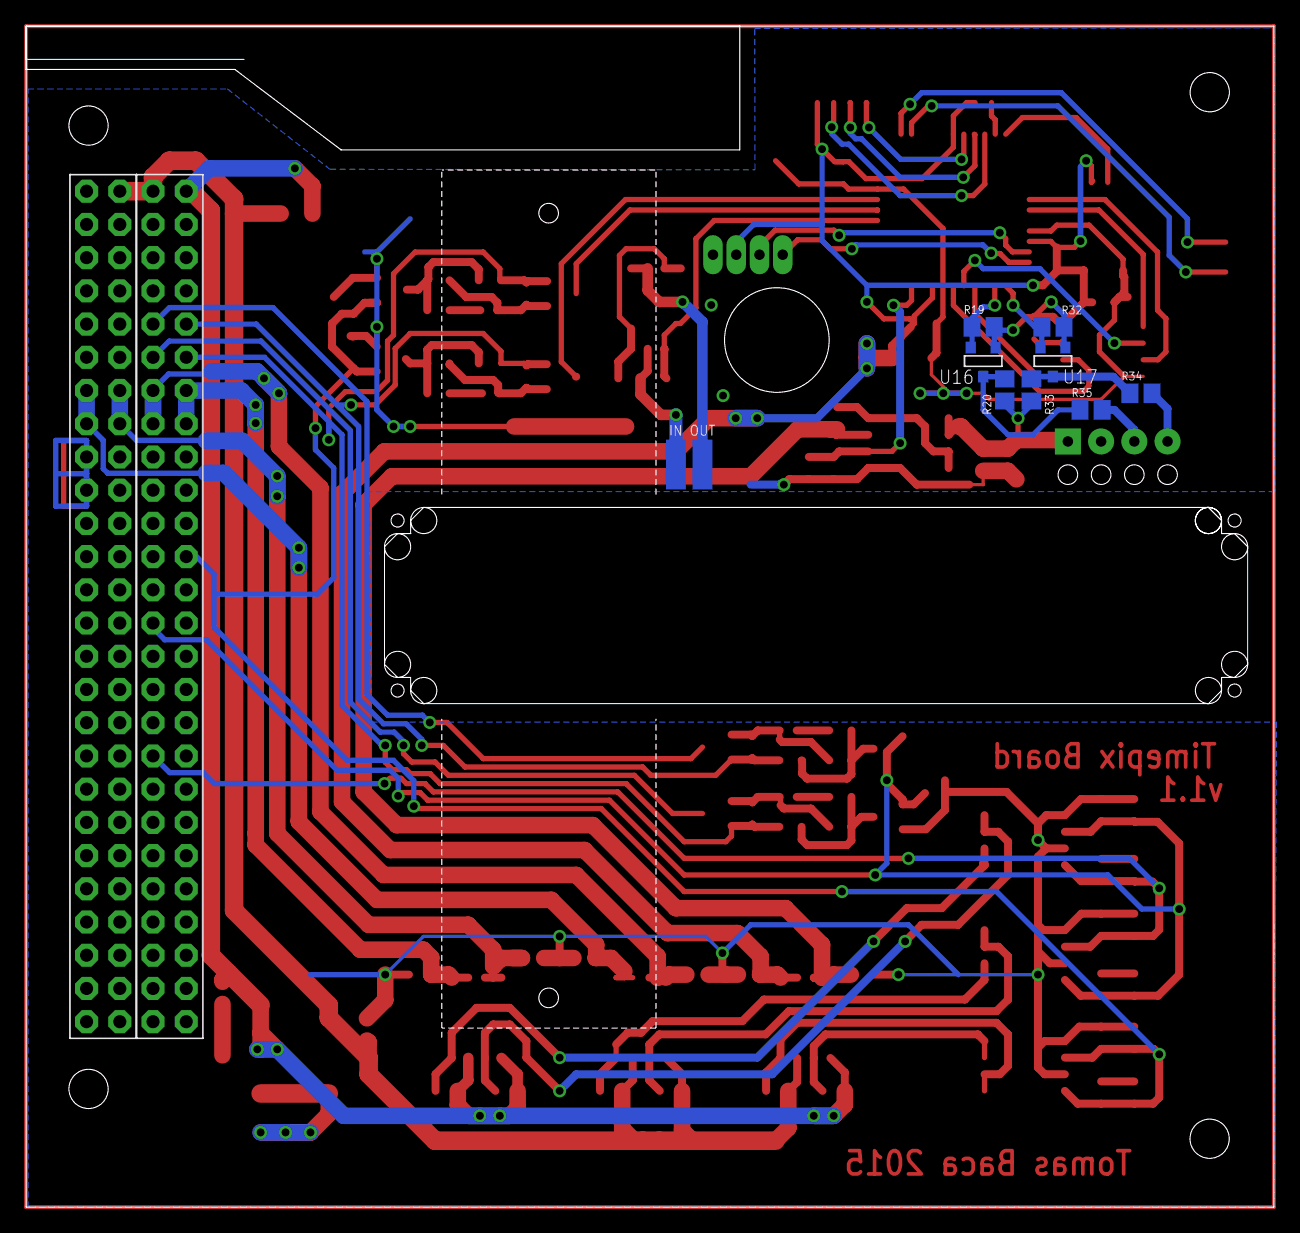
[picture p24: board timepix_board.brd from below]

Board: 2 copper layers, 95.4 x 90.3 mm, 105 parts (12 on the bottom side), 64 nets.

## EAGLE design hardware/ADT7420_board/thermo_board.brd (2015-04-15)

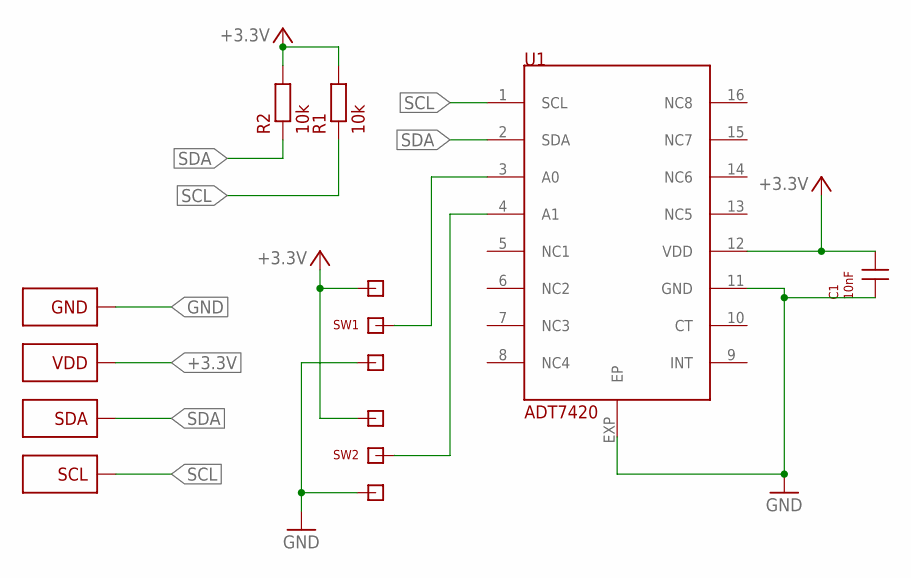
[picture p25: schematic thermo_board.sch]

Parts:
C1: 10nF; R0402
GND: CONN_PAD_SQUARE
R1, R2: 10k; R0402
SCL: CONN_PAD_ROUND
SDA: CONN_PAD_ROUND
SW1, SW2: SOLDER_SWITCH_TWO; SOLDER_SWITCH
U1: ADT7420; LFCSP16
VDD: CONN_PAD_ROUND

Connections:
+3.3V: C1.2, R1.2, R2.2, SW1.1 (2), SW2.1 (2), U1.12 (VDD), VDD.P$1
GND: C1.1, GND.P$1, SW1.2 (1), SW2.2 (1), U1.11 (GND), U1.EXP (EP)
unnamed: SW1.MID, U1.3 (A0)
unnamed: SW2.MID, U1.4 (A1)
SCL: R1.1, SCL.P$1, U1.1 (SCL)
SDA: R2.1, SDA.P$1, U1.2 (SDA)

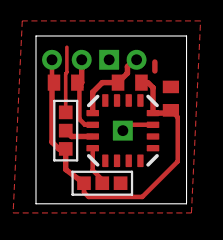
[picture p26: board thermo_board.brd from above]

Board: 2 copper layers, 8.4 x 9.3 mm, 10 parts (0 on the bottom side), 6 nets.

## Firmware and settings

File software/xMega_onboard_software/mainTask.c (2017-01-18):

/*
 * mainTask.c
 *
 * Created: 11.10.2014 20:18:00
 *  Author: Tomas Baca
 */

#include "mainTask.h"
#include "cspTask.h"
#include "system.h"
#include "medipix.h"
#include "equalization.h"
#include "ADT7420.h"
#include "imageProcessing.h"
#include "fram_mapping.h"
#include "errorCodes.h"
#include "medipix.h"
#include "adtTask.h"
#include "spi_memory_FM25.h"
#include "dkHandler.h"
#include "myADC.h"
#include "csp_endian.h"

csp_packet_t * outcomingPacket;
xQueueHandle * xCSPEventQueue;
xQueueHandle * xCSPAckQueue;
xQueueHandle * xCSPTimeQueue;
xQueueHandle * xCSPAttitudeQueue;

unsigned int dest_addr;
unsigned int dest_p;
unsigned int source_p;

char temp[40];

/* The variable used to receive from the queue. */
xCSPStackEvent_t xReceivedEvent;

/* -------------------------------------------------------------------- */
/*	Reply the free heap space in human readable form					*/
/* -------------------------------------------------------------------- */
void sendFreeHeapSpace() {
	
	char msg[20];
	itoa(xPortGetFreeHeapSize(), msg, 10);
	
	/* Copy message to packet */
	strcpy(outcomingPacket->data, msg);
	outcomingPacket->length = strlen(msg);

	csp_sendto(CSP_PRIO_NORM, dest_addr, dest_p, source_p, CSP_O_NONE, outcomingPacket, 1000);
}

void replyErr(uint8_t error) {
	
	vTaskDelay(50);
	
	outcomingPacket->data[0] = 'E';
	outcomingPacket->data[1] = error;
	outcomingPacket->data[2] = '\0';
	
	outcomingPacket->length = 3;
	csp_sendto(CSP_PRIO_NORM, dest_addr, dest_p, source_p, CSP_O_NONE, outcomingPacket, 1000);
	
	vTaskDelay(50);
}

void replyOk() {
	
	vTaskDelay(50);
	
	outcomingPacket->data[0] = 'O';
	outcomingPacket->data[1] = 'K';
	outcomingPacket->data[2] = '\0';
	
	outcomingPacket->length = 3;
	csp_sendto(CSP_PRIO_NORM, dest_addr, dest_p, source_p, CSP_O_NONE, outcomingPacket, 1000);
	
	vTaskDelay(50);
}

uint8_t waitForDkAck() {
	
	vTaskDelay(5);
	
	int32_t err;
	
	if (pdTRUE == xQueueReceive(xCSPAckQueue, &err, 3000)) {
		
		if (err != 0) {
			
			return 0;
		} else {
			
			return 1;
		}
	}

	return 0;
}

/* -------------------------------------------------------------------- */
/*	Reply with some status info message									*/
/* -------------------------------------------------------------------- */
void houseKeeping(uint8_t outputTo) {
	
	loadImageParametersFromFram();
	
	hk_data_t * hk_data;
	dk_msg_store_ack_t * message;
	
	if (outputTo == OUTPUT_DIRECT) {
		
		hk_data = (hk_data_t *) outcomingPacket->data;
	} else {
		
		message = (dk_msg_store_ack_t *) outcomingPacket->data;
		hk_data = (hk_data_t *) message->data;
	}
	
	hk_data->packetType = 'Z';
	hk_data->bootCount = csp_hton16(getBootCount());
	hk_data->imagesTaken = csp_hton16(imageParameters.imageId);
	hk_data->temperature = adt_convert_temperature(ADT_get_temperature());
	hk_data->framStatus = fram_test();
	hk_data->medipixStatus = medipixCheckStatus();
	hk_data->seconds = csp_hton32(secondsTimer);
	hk_data->TIR_max = csp_hton16(uv_ir_data.TIR_max);
	hk_data->TIR_min = csp_hton16(uv_ir_data.TIR_min);
	hk_data->IR_max = csp_hton16(uv_ir_data.IR_max);
	hk_data->IR_min = csp_hton16(uv_ir_data.IR_min);
	hk_data->UV1_max = csp_hton16(uv_ir_data.UV1_max);
	hk_data->UV1_min = csp_hton16(uv_ir_data.UV1_min);
	hk_data->UV2_max = csp_hton16(uv_ir_data.UV2_max);
	hk_data->UV2_min = csp_hton16(uv_ir_data.UV2_min);
	hk_data->temperature_max = adtTemp_max;
	hk_data->temperature_min = adtTemp_min;
	
	// direct answer
	if (outputTo == OUTPUT_DIRECT) {

		outcomingPacket->length = sizeof(hk_data_t);

		csp_sendto(CSP_PRIO_NORM, dest_addr, dest_p, source_p, CSP_O_NONE, outcomingPacket, 1000);
	
	// save it to datakeeper
	} else {
	
		message->parent.cmd = DKC_STORE_ACK;
		message->port = STORAGE_HK_ID;
		message->host = CSP_DK_MY_ADDRESS;
		
		uint8_t k;
		for (k = 0; k < 3; k++) {
			
			outcomingPacket->length = sizeof(dk_msg_store_ack_t) + sizeof(hk_data_t);
			csp_sendto(CSP_PRIO_NORM, CSP_DK_ADDRESS, CSP_DK_PORT, 18, CSP_O_NONE, outcomingPacket, 1000);
			
			if (waitForDkAck() == 1) {
				
				break;
			}
		}
		
		if (k == 3) {
			
			replyErr(ERROR_DATA_NOT_SAVED);
		} else {
			
			replyOk();
		}
	}
}

void medipixInit() {
	
	loadImageParametersFromFram();
	
	if (medipixPowered() == 0)	
		pwrOnMedipix();	

	if (medipixPowered() == 1) {

		loadEqualization(&dataBuffer, &ioBuffer);
		
		eraseMatrix();
		
		setDACs(imageParameters.threshold);
		
		setBias(imageParameters.bias);
	}
}

void medipixStop() {
	
	pwrOffMedipix();
}

void sendImageInfo(uint8_t repplyTo, uint8_t outputForm) {
	
	if (repplyTo == OUTPUT_DIRECT) {

		// load current info from fram
		loadImageParametersFromFram();
		
		imageParameters.outputForm = outputForm;

		imageParameters.packetType = 'A';

		// save current info to the packet
		memcpy(outcomingPacket->data, &imageParameters, sizeof(imageParameters_t));
		
		imageParameters_t * params = (imageParameters_t *) (outcomingPacket->data);
		params->imageId = csp_hton16(params->imageId);
		params->threshold = csp_hton16(params->threshold);
		params->exposure = csp_hton16(params->exposure);
		params->nonZeroPixelsFiltered = csp_hton16(params->nonZeroPixelsFiltered);
		params->nonZeroPixelsOriginal = csp_hton16(params->nonZeroPixelsOriginal);
		params->pixelCountThr = csp_hton16(params->pixelCountThr);
		params->uv1_treshold = csp_hton16(params->uv1_treshold);
		params->chunkId = csp_hton32(params->chunkId);
		
		uint8_t i;
		for (i = 0; i < 7; i++) {
			params->attitude[i] = csp_hton16(params->attitude[i]);
		}
		for (i = 0; i < 3; i++) {
			params->position[i] = csp_hton16(params->position[i]);
		}

		// set the size of the packet
		outcomingPacket->length = sizeof(imageParameters_t);

		// send the final packet
		csp_sendto(CSP_PRIO_NORM, dest_addr, dest_p, source_p, CSP_O_NONE, outcomingPacket, 1000);

		vTaskDelay(100);
		
		// restore current parameters (they have changed)
		loadImageParametersFromFram();
		
	// save data to datakeeper
	} else {
		
		// load current info from fram
		loadImageParametersFromFram();
		
		imageParameters.outputForm = outputForm;
		
		dk_msg_store_ack_t * message = (dk_msg_store_ack_t *) outcomingPacket->data;
		
		imageParameters.packetType = 'A';
		
		message->parent.cmd = DKC_STORE_ACK;
		message->port = STORAGE_METADATA_ID;
		message->host = CSP_DK_MY_ADDRESS;
		
		imageParameters.packetType = 'A';
		
		// save current info to the packet
		memcpy(message->data, &imageParameters, sizeof(imageParameters_t));
		
		uint8_t k;
		for (k = 0; k < 3; k++) {
			
			outcomingPacket->length = sizeof(dk_msg_store_ack_t) + sizeof(imageParameters_t);
			csp_sendto(CSP_PRIO_NORM, CSP_DK_ADDRESS, CSP_DK_PORT, 18, CSP_O_NONE, outcomingPacket, 1000);
			
			if (waitForDkAck() == 1) {
				
				break;
			}
		}

		// restore current parameters (they have changed)
		loadImageParametersFromFram();
	}
}

void waitForAck() {

	xQueueReceive(xCSPEventQueue, &xReceivedEvent, 1500);
}

uint16_t parseUint16(uint8_t * buffer) {
	
	uint16_t value;
	uint8_t * tempPtr;
	
	tempPtr = (uint8_t *) &value;
	
	*tempPtr = buffer[0];
	*(tempPtr+1) = buffer[1];
	
	return value;
}

void saveUint16(uint8_t * buffer, uint16_t value) {
	
	uint8_t * tempPtr = &value;
	
	*buffer = *tempPtr;
	*(buffer+1) = *(tempPtr+1);
}

// image == 0 -> original
// image == 1 -> compressed
uint8_t sendCompressed(uint8_t image, uint8_t replyTo) {
	
	uint8_t (*getPixel)(uint8_t, uint8_t);
	
	if (image == 0)
		getPixel = &getRawPixel;
	else
		getPixel = &getFilteredPixel;
	
	uint16_t i, j;
	
	uint8_t packetPointer, tempPixel, numPixelsInPacket;
	
	uint8_t noErr = 1;
	
	if (imageParameters.nonZeroPixelsOriginal == 0)
		return 0;
		
	if (replyTo == OUTPUT_DIRECT) {
	
		// initialize the first packet
		outcomingPacket->data[0] = 'B';
		saveUint16(outcomingPacket->data+1, imageParameters.imageId);
		packetPointer = 4;
		numPixelsInPacket = 0;
	
		for (i = 0; i < 256; i++) {
		
			for (j = 0; j < 256; j++) {
			
				tempPixel = getPixel(i, j);
			
				// the pixel will be send
				if (tempPixel > 0) {
				
					// there is still a place in the packet
					if (packetPointer <= 61) {
					
						saveUint16(outcomingPacket->data + packetPointer, i*256+j);
						packetPointer += 2;
						*(outcomingPacket->data + packetPointer++) = tempPixel;
						numPixelsInPacket++;
					}
				
					// the packet is full, send it
					if (packetPointer > 61) {
					
						outcomingPacket->data[3] = numPixelsInPacket;
						outcomingPacket->length = packetPointer;
						csp_sendto(CSP_PRIO_NORM, dest_addr, dest_p, source_p, CSP_O_NONE, outcomingPacket, 1000);
					
						waitForAck();
					
						outcomingPacket->data[0] = 'B';
						saveUint16(outcomingPacket->data+1, imageParameters.imageId);
						packetPointer = 4;
						numPixelsInPacket = 0;
					}
				}
			}
		}
	
		// send the last data packet
		if (packetPointer > 4) {
		
			outcomingPacket->length = packetPointer;
			outcomingPacket->data[3] = numPixelsInPacket;
			csp_sendto(CSP_PRIO_NORM, dest_addr, dest_p, source_p, CSP_O_NONE, outcomingPacket, 1000);
		}
	
		waitForAck();
		
		vTaskDelay(20);
	
		// send the terminal packet
		outcomingPacket->data[0] = 'C';
		outcomingPacket->length = 1;
	
		csp_sendto(CSP_PRIO_NORM, dest_addr, dest_p, source_p, CSP_O_NONE, outcomingPacket, 1000);
	
		waitForAck();
	
		return 1;
	
	// output to DK
	} else {
		
		dk_msg_store_ack_t * message = (dk_msg_store_ack_t *) outcomingPacket->data;
	
		message->parent.cmd = DKC_STORE_ACK;
		message->port = STORAGE_DATA_ID;
		message->host = CSP_DK_MY_ADDRESS;
		
		// initialize the first packet
		message->data[0] = 'B';
		saveUint16(message->data+1, imageParameters.imageId);
		packetPointer = 4;
		numPixelsInPacket = 0;
		
		for (i = 0; i < 256; i++) {
			
			for (j = 0; j < 256; j++) {
				
				tempPixel = getPixel(i, j);
				
				// the pixel will be send
				if (tempPixel > 0) {
					
					// there is still a place in the packet
					if (packetPointer <= 61) {
						
						saveUint16(message->data + packetPointer, i*256+j);
						packetPointer += 2;
						*(message->data + packetPointer++) = tempPixel;
						numPixelsInPacket++;
					}
					
					// the packet is full, send it
					if (packetPointer > 61) {
						
						message->data[3] = numPixelsInPacket;
						
						uint8_t k;
						for (k = 0; k < 3; k++) {
						
							outcomingPacket->length = packetPointer + sizeof(dk_msg_store_ack_t);
							csp_sendto(CSP_PRIO_NORM, CSP_DK_ADDRESS, CSP_DK_PORT, 18, CSP_O_NONE, outcomingPacket, 1000);
							
							if (waitForDkAck() == 1) {
								
								break;
							}
						}
						
						if (k == 3) {
							
							noErr *= 0;
						}
						
						message->data[0] = 'B';
						saveUint16(message->data+1, imageParameters.imageId);
						packetPointer = 4;
						numPixelsInPacket = 0;
					}
				}
			}
		}
		
		// send the last data packet
		if (packetPointer > 4) {
			
			message->data[3] = numPixelsInPacket;
			
			uint8_t k;
			for (k = 0; k < 3; k++) {	
				
				outcomingPacket->length = packetPointer + sizeof(dk_msg_store_ack_t);
				csp_sendto(CSP_PRIO_NORM, CSP_DK_ADDRESS, CSP_DK_PORT, 18, CSP_O_NONE, outcomingPacket, 1000);
				
				if (waitForDkAck() == 1) {
								
					break;
				}
			}
						
			if (k == 3) {
							
				noErr *= 0;
			}
		}

		return noErr;
	}

}

void sendPostProcessed(uint8_t replyTo, uint8_t outputForm) {
	
	uint16_t i, j;
	
	uint16_t numPerLine = 0;
	
	dk_msg_store_ack_t * message = (dk_msg_store_ack_t *) outcomingPacket->data;
	
	uint8_t noErr = 1;
	
	switch (outputForm) {
		
		case BINNING_8:
			numPerLine = 32;
		break;
		
		case BINNING_16:
			numPerLine = 16;
		break;
		
		case BINNING_32:
			numPerLine = 8;
		break;
	}
	
	// if saving data to datakeeper, set the correct data storage
	if (replyTo == OUTPUT_DATAKEEPER) {
		
		message->parent.cmd = DKC_STORE_ACK;
		message->port = STORAGE_DATA_ID;
		message->host = CSP_DK_MY_ADDRESS;
	}
	
	// send the energy histogram
	if (outputForm == ENERGY_HISTOGRAM) {
		
		if (replyTo == OUTPUT_DIRECT) {
			
			// it is a first histogram packet [0]
			outcomingPacket->data[0] = 'e';
			
			// save the image ID [1, 2]
			saveUint16(outcomingPacket->data+1, imageParameters.imageId);
				
			// fill the packets
			for (j = 0; j < 32; j++) {
					
				outcomingPacket->data[j+3] = spi_mem_read_byte((unsigned long) (ENERGY_HISTOGRAM_ADRESS + j));
			}
				
			outcomingPacket->length = 32 + 3;
				
			csp_sendto(CSP_PRIO_NORM, dest_addr, dest_p, source_p, CSP_O_NONE, outcomingPacket, 1000);
				
			waitForAck();

		} else {

			// it is a first histogram packet [0]
			message->data[0] = 'e';
			
			// save the image ID [1, 2]
			saveUint16(message->data+1, imageParameters.imageId);
			
			// fill the packets
			for (j = 0; j < 32; j++) {
				
				message->data[j+3] = spi_mem_read_byte((unsigned long) (ENERGY_HISTOGRAM_ADRESS + j));
			}
				
			uint8_t k;
			for (k = 0; k < 3; k++) {
					
				outcomingPacket->length = 32 + 3 + sizeof(dk_msg_store_ack_t);
				csp_sendto(CSP_PRIO_NORM, CSP_DK_ADDRESS, CSP_DK_PORT, 18, CSP_O_NONE, outcomingPacket, 1000);
					
				if (waitForDkAck() == 1) {
						
					break;
				}
			}
				
			if (k == 3) {
					
				noErr *= 0;
			}
		}
		
	} else if (outputForm == HISTOGRAMS) {
		
		if (replyTo == OUTPUT_DIRECT) {
			
			// send the 1st histogram
			// for 4 packets
			for (i = 0; i < 4; i++) {
			
				// it is a first histogram packet [0]
				outcomingPacket->data[0] = 'h';
			
				// save the image ID [1, 2]
				saveUint16(outcomingPacket->data+1, imageParameters.imageId);
			
				// save the number of the packet
				outcomingPacket->data[3] = i;
			
				// fill the packets
				for (j = 0; j < 64; j++) {
				
					outcomingPacket->data[j+4] = getHistogram1(j + i*64);
				}
			
				outcomingPacket->length = 64 + 4;
			
				csp_sendto(CSP_PRIO_NORM, dest_addr, dest_p, source_p, CSP_O_NONE, outcomingPacket, 1000);
			
				waitForAck();
			}
		
			// send the 2nd histogram
			// for 4 packets
			for (i = 0; i < 4; i++) {
			
				// it is a first histogram packet [0]
				outcomingPacket->data[0] = 'H';
			
				// save the image ID [1, 2]
				saveUint16(outcomingPacket->data+1, imageParameters.imageId);
			
				// save the number of the packet
				outcomingPacket->data[3] = i;
			
				// fill the packets
				for (j = 0; j < 64; j++) {
				
					outcomingPacket->data[j+4] = getHistogram2(j + i*64);
				}
			
				outcomingPacket->length = 64 + 4;
			
				csp_sendto(CSP_PRIO_NORM, dest_addr, dest_p, source_p, CSP_O_NONE, outcomingPacket, 1000);
			
				waitForAck();
			}
		} else {
			
			// send the 1st histogram
			// for 4 packets
			for (i = 0; i < 4; i++) {
				
				// it is a first histogram packet [0]
				message->data[0] = 'h';
				
				// save the image ID [1, 2]
				saveUint16(message->data+1, imageParameters.imageId);
				
				// save the number of the packet
				message->data[3] = i;
				
				// fill the packets
				for (j = 0; j < 64; j++) {
					
					message->data[j+4] = getHistogram1(j + i*64);
				}
				
				uint8_t k;
				for (k = 0; k < 3; k++) {
					
					outcomingPacket->length = 64 + 4 + sizeof(dk_msg_store_ack_t);
					csp_sendto(CSP_PRIO_NORM, CSP_DK_ADDRESS, CSP_DK_PORT, 18, CSP_O_NONE, outcomingPacket, 1000);
					
					if (waitForDkAck() == 1) {
						
						break;
					}
				}
				
				if (k == 3) {
					
					noErr *= 0;
				}
			}
			
			// send the 2nd histogram
			// for 4 packets
			for (i = 0; i < 4; i++) {
				
				// it is a first histogram packet [0]
				message->data[0] = 'H';
				
				// save the image ID [1, 2]
				saveUint16(message->data+1, imageParameters.imageId);
				
				// save the number of the packet
				message->data[3] = i;
				
				// fill the packets
				for (j = 0; j < 64; j++) {
					
					message->data[j+4] = getHistogram2(j + i*64);
				}
				
				uint8_t k;
				for (k = 0; k < 3; k++) {
							
					outcomingPacket->length = 64 + 4 + sizeof(dk_msg_store_ack_t);
					csp_sendto(CSP_PRIO_NORM, CSP_DK_ADDRESS, CSP_DK_PORT, 18, CSP_O_NONE, outcomingPacket, 1000);
							
					if (waitForDkAck() == 1) {
								
						break;
					}
				}
						
				if (k == 3) {
							
					noErr *= 0;
				}
			}
		}
		
	// send the binned content
	} else if (outputForm >= BINNING_8 && outputForm <= BINNING_32) {
		
		uint8_t packetId = 0;
		uint8_t byteInPacket = 0;
		uint8_t outId = 0;
		
		if (outputForm == BINNING_8)
			outId = 'D';
		else if (outputForm == BINNING_16)
			outId = 'E';
		else if (outputForm == BINNING_32)
			outId = 'F';
		
		if (replyTo == OUTPUT_DIRECT) {
		
			// it is a first histogram packet [0]
		
			// save the image ID [1, 2]
			saveUint16(outcomingPacket->data+1, imageParameters.imageId);
			
			outcomingPacket->data[0] = outId;
		
			// bytes count
			outcomingPacket->data[3] = packetId++;
		
			for (i = 0; i < numPerLine; i++) {
			
				for (j = 0; j < numPerLine; j++) {
				
					outcomingPacket->data[4+byteInPacket++] = getBinnedPixel(i, j, outputForm);
				
					// packet is full, send it
					if (byteInPacket == 64) {
					
						outcomingPacket->length = 64 + 4;
					
						csp_sendto(CSP_PRIO_NORM, dest_addr, dest_p, source_p, CSP_O_NONE, outcomingPacket, 1000);
					
						waitForAck();
					
						byteInPacket = 0;
					
						outcomingPacket->data[3] = packetId++;
					}
				}
			}
			
		// save to datakeeper
		} else {
			
			// it is a first histogram packet [0]
			message->data[0] = outId;
			
			// save the image ID [1, 2]
			saveUint16(message->data+1, imageParameters.imageId);
			
			// bytes count
			message->data[3] = packetId++;
			
			for (i = 0; i < numPerLine; i++) {
				
				for (j = 0; j < numPerLine; j++) {
					
					message->data[4+byteInPacket++] = getBinnedPixel(i, j, outputForm);
					
					// packet is full, send it
					if (byteInPacket == 64) {
						
						uint8_t k;
						for (k = 0; k < 3; k++) {
							
							outcomingPacket->length = 64 + 4 + sizeof(dk_msg_store_ack_t);
							csp_sendto(CSP_PRIO_NORM, CSP_DK_ADDRESS, CSP_DK_PORT, 18, CSP_O_NONE, outcomingPacket, 1000);
							
							if (waitForDkAck() == 1) {
								
								break;
							}
						}
						
						if (k == 3) {
							
							noErr *= 0;
						}
						
						byteInPacket = 0;
						
						message->data[3] = packetId++;
					}
				}
			}
		}
	}
}

void shutterDelay() {
	
	if (imageParameters.exposure <= (uint16_t) 60000) {
		
		vTaskDelay(imageParameters.exposure);	
	} else {
		
		vTaskDelay((uint16_t) 60000);
		
		uint16_t i;
		
		for (i = 0; i < (imageParameters.exposure - 60000); i++) {
			
			vTaskDelay(1000);
		}
	}
}

uint32_t getNextChunkId(uint8_t port) {
	
	dk_msg_storage_t * message = (dk_msg_storage_t *) outcomingPacket->data;
	
	message->host = CSP_DK_MY_ADDRESS;
	message->port = STORAGE_DATA_ID;
	message->parent.cmd = DKC_INFO;
	
	uint32_t chunksNum;
	
	uint8_t i;
	for (i = 0; i < 3; i++) {
		
		outcomingPacket->length = sizeof(dk_msg_storage_t);
		
		csp_sendto(CSP_PRIO_NORM, CSP_DK_ADDRESS, CSP_DK_PORT, 21, CSP_O_NONE, outcomingPacket, 1000);
		
		chunksNum = csp_hton32(waitForTimeAck());
		
		if (chunksNum > 0) {
				
			break;
		}	
	}
	
	if (chunksNum == 0)
		return 0;
		
	return chunksNum + 1;
}

uint8_t measure(uint8_t turnOff, uint8_t withoutData, uint8_t repplyTo, uint8_t usePixelTreshold) {
	
	char inChar;
	
	if (medipixPowered() == 0) {
		
		medipixInit();
	}
	
	// pokud se nepustil
	if (medipixPowered() == 0) {
		
		// zalogovat chybu
		return 0;
	}
	
	loadImageParametersFromFram();
	
	openShutter();
	
	shutterDelay();
	
	closeShutter();
	
	vTaskDelay(10);
	
	readMatrix();
	
	while (usartBufferGetByte(medipix_usart_buffer, &inChar, 1)) {}

	if (turnOff == MEASURE_TURNOFF_YES) {
		
		medipixStop();
	}

	imageParameters.temperature = adtTemp;
	
	imageParameters.time = getTime();

	getAttitude(&imageParameters.attitude, &imageParameters.position);

	filterOnePixelEvents();

	computeImageStatistics();

	if (usePixelTreshold == 1) {
		
		if (imageParameters.nonZeroPixelsFiltered < imageParameters.pixelCountThr) {
			
			return 0;
		}
	}

	// increase image id
	imageParameters.imageId++;
	saveImageParametersToFram();
	
	/* ZDE KONÈÍ VYÈÍTÁNÍ OBRÁZKU */
	
	// no data output, just save metadata
	if (imageParameters.outputForm == 0) {
		
		imageParameters.chunkId = 0;
		saveImageParametersToFram();
		sendImageInfo(repplyTo, 0);
	}
	
	// BINING_32
	if ((imageParameters.outputForm & 0x08) > 0) {
		
		applyBinning(BINNING_32);
		imageParameters.chunkId = getNextChunkId(STORAGE_DATA_ID);
		saveImageParametersToFram();
		sendImageInfo(repplyTo, BINNING_32);
		sendPostProcessed(repplyTo, BINNING_32);
	}

	// BINING_16
	if ((imageParameters.outputForm & 0x04) > 0) {
	
		applyBinning(BINNING_16);
		imageParameters.chunkId = getNextChunkId(STORAGE_DATA_ID);
		saveImageParametersToFram();
		sendImageInfo(repplyTo, BINNING_16);
		sendPostProcessed(repplyTo, BINNING_16);
	}

	// BINING_8
	if ((imageParameters.outputForm & 0x02) > 0) {

		applyBinning(BINNING_8);
		imageParameters.chunkId = getNextChunkId(STORAGE_DATA_ID);
		saveImageParametersToFram();
		sendImageInfo(repplyTo, BINNING_8);
		sendPostProcessed(repplyTo, BINNING_8);
	}

	// HISTOGRAMY
	if ((imageParameters.outputForm & 0x10) > 0) {
	
		createHistograms(HISTOGRAMS);
		imageParameters.chunkId = getNextChunkId(STORAGE_DATA_ID);
		saveImageParametersToFram();
		sendImageInfo(repplyTo, HISTOGRAMS);
		sendPostProcessed(repplyTo, HISTOGRAMS);
	}

	// ENERGY_HISTOGRAM
	if ((imageParameters.outputForm & 0x20) > 0) {
	
		createEnergyHistogram();
		imageParameters.chunkId = getNextChunkId(STORAGE_DATA_ID);
		saveImageParametersToFram();
		sendImageInfo(repplyTo, ENERGY_HISTOGRAM);
		sendPostProcessed(repplyTo, ENERGY_HISTOGRAM);
	}
	
	// BINING_1
	if ((imageParameters.outputForm & 0x01) > 0) {
		
		applyBinning(BINNING_1);
		imageParameters.chunkId = getNextChunkId(STORAGE_DATA_ID);
		saveImageParametersToFram();
		sendImageInfo(repplyTo, BINNING_1);
		sendCompressed(1, repplyTo);
	}

	return 1;
}
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

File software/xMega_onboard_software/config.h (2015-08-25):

/*
 * config.h
 *
 * Created: 11.10.2014 18:31:37
 *  Author: Tomas Baca
 */ 

#ifndef CONFIG_H_
#define CONFIG_H_

#include "twi_master_driver.h"

// define different versions of timepix
// #define MEDIPIX_EQM	1			// EQM 
#define MEDIPIX_FLIGHT	1			// LETOVY kus

#define DEBUG_OUTPUT 1
#define MATLAB_OUTPUT 1

#define PLOT_TEST_PATTERN 0

// Address of the local CSP node
#define CSP_MY_ADDRESS	4		// Deska Medipix

// Address of the OBC CSP node
#define CSP_OBC_ADDRESS		1	

// Adress of the radio
#define CSP_RADIO_ADDRESS	5

#define CSP_DEBUG_ADRESS	30

// Actual position of CSP i2c on the xMega
// Replace "TWIE" with adequate port of your board
#define CSP_I2C_INTERFACE	TWIE
#define CSP_I2C_TWIM		TWIE_TWIM_vect
#define CSP_I2C_TWIS		TWIE_TWIS_vect

// Slave address of my CSP i2c interface
#define CSP_I2C_SLAVE_ADDRESS	CSP_MY_ADDRESS

// Slave address of the OBC CSP i2c interface
#define CSP_I2C_OBC_ADDRESS	CSP_OBC_ADDRESS

// slave address of the RADIO on the i2c
#define CSP_I2C_COM_ADRESS	CSP_RADIO_ADDRESS

// Number of CSP buffer to allocate
#define CSP_BUFFER_COUNT	1

// CSP Buffer size in bytes
#define CSP_BUFFER_SIZE	98

// Maximum size of CSP packet, payload + header
#define CSP_PACKET_SIZE	84

// Size of CSP router stack in words
#define CSP_ROUTER_STACK	256

// Do not ever change!!!
#define CSP_ROUTER_PRIORITY	0

// Baudrate of the CSP i2c interface
#define CSP_I2C_BAUDRATE	400000
#define CSP_I2C_BAUDSETTING TWI_BAUD(F_CPU, CSP_I2C_BAUDRATE)

// define the usart port for MEDIPIX
#define MPX_USART	USARTC0

#define MPX_USART_BAUDRATE	BAUD200000

#define MPX_USART_BUFFERSIZE	255

// definitions for ADT7420 thermometer IC
#define ADT_I2C_INTERFACE	TWIC
#define ADT_I2C_TWIM		TWIC_TWIM_vect
#define ADT_I2C_BAUDRATE	400000
#define ADT_I2C_ADDRESS		0x48

// definition for SPI memory - interface, CS pin must be edited in spi_memory_23lcxx.c
// letovy kus
#define SPI_MEM_INTERFACE	SPIC
#define SPI_PORT			PORTC

#endif /* CONFIG_H_ */

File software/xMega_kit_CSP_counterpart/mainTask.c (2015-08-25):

/*
 * mainTask.c
 *
 * Created: 11.10.2014 20:18:00
 *  Author: Tomas Baca
 */

#include "mainTask.h"
#include "cspTask.h"
#include "system.h"
#include "queue.h"
#include "usart_driver_RTOS.h"
#include "medipixHeaders.h"

// to save outcomming time of ping
uint32_t pingSent;

// for ping time difference
int16_t timediff;

uint8_t * ptr;

newSettings_t settings;

/* -------------------------------------------------------------------- */
/*	The main task														*/
/* -------------------------------------------------------------------- */
void mainTask(void *p) {
	
	settings.treshold = 250;
	settings.exposure = 1000;
	settings.bias = 109;
	settings.filtering = FILTERING_ON;
	settings.mode = MODE_MEDIPIX;
	settings.outputForm = BINNING_1;
		
	// packet used to handle incoming communication
	csp_packet_t * outcomingPacket = csp_buffer_get(CSP_PACKET_SIZE);

	// character received from uart
	char inChar;
	
	/* The variable used to receive from the queue. */
	xCSPStackEvent_t xReceivedEvent;
	
	int i; // iterator
	
	// text buffer for uart
	char text[20];
	
	// infinite while loop of the program 
	while (1) {
		
		if (xQueueReceive(xCSPEventQueue, &xReceivedEvent, 1)) {
			
			switch (xReceivedEvent.eEventType) {
			
				case generalCommEvent:
			
					// send its content to the uart
					for (i = 0; i < ((csp_packet_t *) xReceivedEvent.pvData)->length; i++) {
						usartBufferPutByte(pc_usart_buffer, ((csp_packet_t *) xReceivedEvent.pvData)->data[i], 10);
					}
			
				break;
				case pingReceivedEvent:
			
					// calculate the ping return time
					if ((int16_t) milisecondsTimer - (int16_t) pingSent > 0)
						timediff = milisecondsTimer - pingSent;
					else
						timediff = (int16_t) milisecondsTimer - (int16_t) pingSent + (int16_t) 1000;

					itoa(timediff, text, 10);
					usartBufferPutString(pc_usart_buffer, "ping received in ", 10);
					usartBufferPutString(pc_usart_buffer, text, 10);
					usartBufferPutString(pc_usart_buffer, "ms\n\r", 10);
			
				break;
				
				case dataPacketEvent:
				
					// send its content to the uart
					for (i = 0; i < ((csp_packet_t *) xReceivedEvent.pvData)->length; i++) {
						usartBufferPutByte(pc_usart_buffer, ((csp_packet_t *) xReceivedEvent.pvData)->data[i], 10);
					}
					
					usartBufferPutString(pc_usart_buffer, "\r\n", 10);
				
				break;
			
				default:
					/* Should not get here. */
				break;
			}
		}
		
		// if there is something from the uart
		if (usartBufferGetByte(pc_usart_buffer, &inChar, 0)) {
		
			outcomingPacket->data[0] = inChar;
			outcomingPacket->length = 1;
			uint8_t k;
			
			uint8_t * tempPtr = (uint8_t) &settings;
			unsigned char inChar2;
		
			switch (inChar) {
			
				// turn on medipix
				case '0':
					outcomingPacket->data[0] = MEDIPIX_PWR_ON;
					outcomingPacket->length = 1;
					csp_sendto(CSP_PRIO_NORM, CSP_BOARD_ADDRESS, 16, 17, CSP_O_NONE, outcomingPacket, 10);
				break;
			
				// power off medipix
				case '1':
					outcomingPacket->data[0] = MEDIPIX_PWR_OFF;
					outcomingPacket->length = 1;
					csp_sendto(CSP_PRIO_NORM, CSP_BOARD_ADDRESS, 16, 17, CSP_O_NONE, outcomingPacket, 10);
				break;
				
				// set parameters
				case '2':
				
					tempPtr = &settings;
				
					// receive the parameters over the uart
					for (k = 0; k < sizeof(newSettings_t); k++) {
					
						if (usartBufferGetByte(pc_usart_buffer, &inChar, 1000)) {
							
							*(tempPtr+k) = inChar;
						}
					}
				
					outcomingPacket->data[0] = MEDIPIX_SET_ALL_PARAMS;
					
					memcpy(outcomingPacket->data+1, &settings, sizeof(newSettings_t));
					
					outcomingPacket->length = 1+sizeof(newSettings_t);
					
					csp_sendto(CSP_PRIO_NORM, CSP_BOARD_ADDRESS, 16, 17, CSP_O_NONE, outcomingPacket, 10);
					
				break;
				
				// set treshold
				case '3':
				
					usartBufferGetByte(pc_usart_buffer, outcomingPacket->data+1, 1000);
					usartBufferGetByte(pc_usart_buffer, outcomingPacket->data+2, 1000);
											
					outcomingPacket->data[0] = MEDIPIX_SET_THRESHOLD;
					
					outcomingPacket->length = 1+2;
					
					csp_sendto(CSP_PRIO_NORM, CSP_BOARD_ADDRESS, 16, 17, CSP_O_NONE, outcomingPacket, 10);
				
				break;
				
				// set bias
				case '4':
				
					usartBufferGetByte(pc_usart_buffer, outcomingPacket->data+1, 1000);
					
					outcomingPacket->data[0] = MEDIPIX_SET_BIAS;
					
					outcomingPacket->length = 1+1;
					
					csp_sendto(CSP_PRIO_NORM, CSP_BOARD_ADDRESS, 16, 17, CSP_O_NONE, outcomingPacket, 10);
				
				break;
				
				// set exposure
				case '5':
				
					usartBufferGetByte(pc_usart_buffer, outcomingPacket->data+1, 1000);
					usartBufferGetByte(pc_usart_buffer, outcomingPacket->data+2, 1000);
					
					outcomingPacket->data[0] = MEDIPIX_SET_EXPOSURE;
					
					outcomingPacket->length = 1+2;
					
					csp_sendto(CSP_PRIO_NORM, CSP_BOARD_ADDRESS, 16, 17, CSP_O_NONE, outcomingPacket, 10);
				
				break;
				
				// set filtering
				case '6':
				
					usartBufferGetByte(pc_usart_buffer, outcomingPacket->data+1, 1000);
					
					outcomingPacket->data[0] = MEDIPIX_SET_FILTERING;
					
					outcomingPacket->length = 1+1;
					
					csp_sendto(CSP_PRIO_NORM, CSP_BOARD_ADDRESS, 16, 17, CSP_O_NONE, outcomingPacket, 10);
				
				break;
				
				// set mode
				case '7':
				
					usartBufferGetByte(pc_usart_buffer, outcomingPacket->data+1, 1000);
					
					outcomingPacket->data[0] = MEDIPIX_SET_MODE;
					
					outcomingPacket->length = 1+1;
					
					csp_sendto(CSP_PRIO_NORM, CSP_BOARD_ADDRESS, 16, 17, CSP_O_NONE, outcomingPacket, 10);
				
				break;
				
				// set output form
				case '8':
				
					usartBufferGetByte(pc_usart_buffer, outcomingPacket->data+1, 1000);
					
					outcomingPacket->data[0] = MEDIPIX_SET_OUTPUT_FORM;
					
					outcomingPacket->length = 1+1;
					
					csp_sendto(CSP_PRIO_NORM, CSP_BOARD_ADDRESS, 16, 17, CSP_O_NONE, outcomingPacket, 10);
				
				break;
				
				// measure 
				case '9':
				
					outcomingPacket->data[0] = MEDIPIX_MEASURE;
					
					outcomingPacket->length = 1;
					
					csp_sendto(CSP_PRIO_NORM, CSP_BOARD_ADDRESS, 16, 17, CSP_O_NONE, outcomingPacket, 10);
					
				break;
				
				// measure no turn off
				case 'q':
				
					outcomingPacket->data[0] = MEDIPIX_MEASURE_NO_TURNOFF;
					
					outcomingPacket->length = 1;
					
					csp_sendto(CSP_PRIO_NORM, CSP_BOARD_ADDRESS, 16, 17, CSP_O_NONE, outcomingPacket, 10);
				
				break;
				
				// read original image
				case 'e':
				
					outcomingPacket->data[0] = MEDIPIX_SEND_ORIGINAL;
					
					outcomingPacket->length = 1;
					
					csp_sendto(CSP_PRIO_NORM, CSP_BOARD_ADDRESS, 16, 17, CSP_O_NONE, outcomingPacket, 10);

				break;
				
				// read filtered image
				case 'r':
				
					outcomingPacket->data[0] = MEDIPIX_SEND_FILTERED;
					
					outcomingPacket->length = 1;
					
					csp_sendto(CSP_PRIO_NORM, CSP_BOARD_ADDRESS, 16, 17, CSP_O_NONE, outcomingPacket, 10);
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

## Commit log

2014-11-02 CSP working with OBC
    + BAUDrate fix
    + HouseKeeping routine
    + some other fixes
    [config.h, csp_interface.c, main.c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]
2014-11-02 Branch created
    [cooler1.dwg, medipix.brd, medipix.sch]
2014-11-12 + Medipix switch
2015-02-11 + new connectors, + medipix 2.2V switch
    [medipix.sch]
2015-02-15 Medipix readout working properly
    [medipix.brd]
2015-02-22 + Board updated with temperature sensor connector
    [medipix.brd, medipix.sch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]
2015-03-01 Deska pro teplomer
    [thermo_board.brd, thermo_board.sch]
2015-03-03 Thermo board sent out
    [thermo_board.brd]
2015-04-15 Thermo board dalsi podklady
    [thermo_board.brd, thermo_board.sch]
2015-06-08 + mask and printing script
2015-06-25 Towards the filtering
2015-06-25 Filtering works
2015-06-30 Delays during startup shortened, exposition time fixed
    [config.h]
2015-07-02 Equalization Fixed, Bias fixe, Thr fixe, all fixed
    [config.h]
2015-07-02 Many fixes, Bias and Thr loading during startup
    [mainTask.c]
2015-07-03 Equalization depending on the mounted medipix
2015-07-04 Matlab reworked, Last two line of the detector fixed
    [ADT7420.c, config.h, mainTask.c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]
2015-07-06 ADT negative values fixed
    [ADT7420.c, mainTask.c]
2015-07-07 HK and medipix message correctly saving to DK with ACK
    [dkHandler.h, mainTask.c]
2015-07-16 + UV and IR sensors
2015-07-16 sensor re-typed to signed int
2015-09-03 Upgrade FW in the flight board
2015-09-28 + mereni 21.9.2015
    New optics tested in vacuum chamber with X-Ray source.
2016-01-22 Bug fix with sensors minmax
    Flashed to VZLUSAT-1 at 21.1.2016
    [myADC.c]
2016-02-15 Bug fix
    + fixed bug with uninitialized pointer in ComTask
    + prolonged timeout for getTime
    + added 5ms timeout to waitForDkAck
    [mainTask.c]
2017-03-27 + first prototype of pyDecode
2017-03-29 partially working calibration
2019-07-08 added assembly firmware for USB Lite
    [Medipix.OBJ]
2021-01-03 polishing repo structure
    [timepix_board.brd, timepix_board.sch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]

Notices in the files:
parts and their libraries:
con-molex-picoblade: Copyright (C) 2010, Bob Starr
